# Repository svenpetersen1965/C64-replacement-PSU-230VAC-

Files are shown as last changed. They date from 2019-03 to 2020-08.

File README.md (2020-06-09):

# C64-replacement-PSU-230VAC-
This is a replacement PSU for the Commodore C64. The original PSUs from the 1980s and early 1990s tend to die and damage the connected C64, so it is recommended to get a new power supply for the C64.
This design is straight forward: a transformer, bridge rectifier and DC/DC converter for the 5VDC and a separat winding for the 9VAC. Nothing fancy. It was paid attention to use parts which are easily available (in Germany). Everything, except the 4 conductor cable for the output voltage are sourced from reichelt.de.
A further goal was a decent documentation.

Find some info on the required cable making <a href="http://tech.guitarsite.de/cable_making.html">on my website</a>

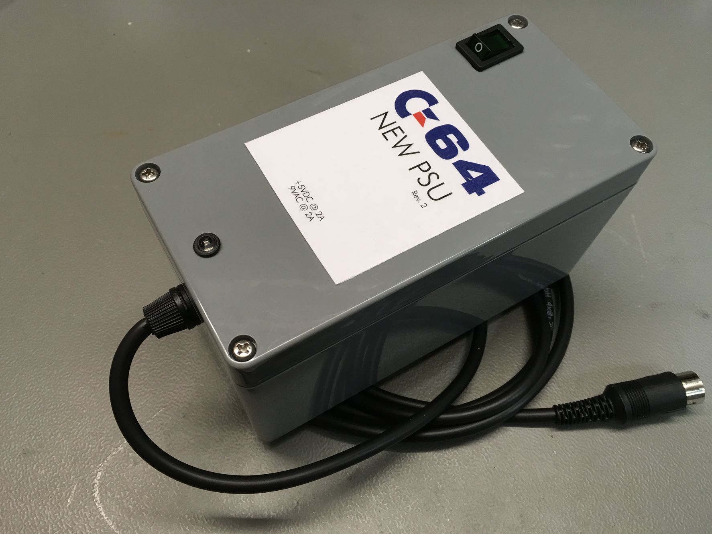
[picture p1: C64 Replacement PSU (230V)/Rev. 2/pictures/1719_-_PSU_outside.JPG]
C64 replacement PSU (outside)

      
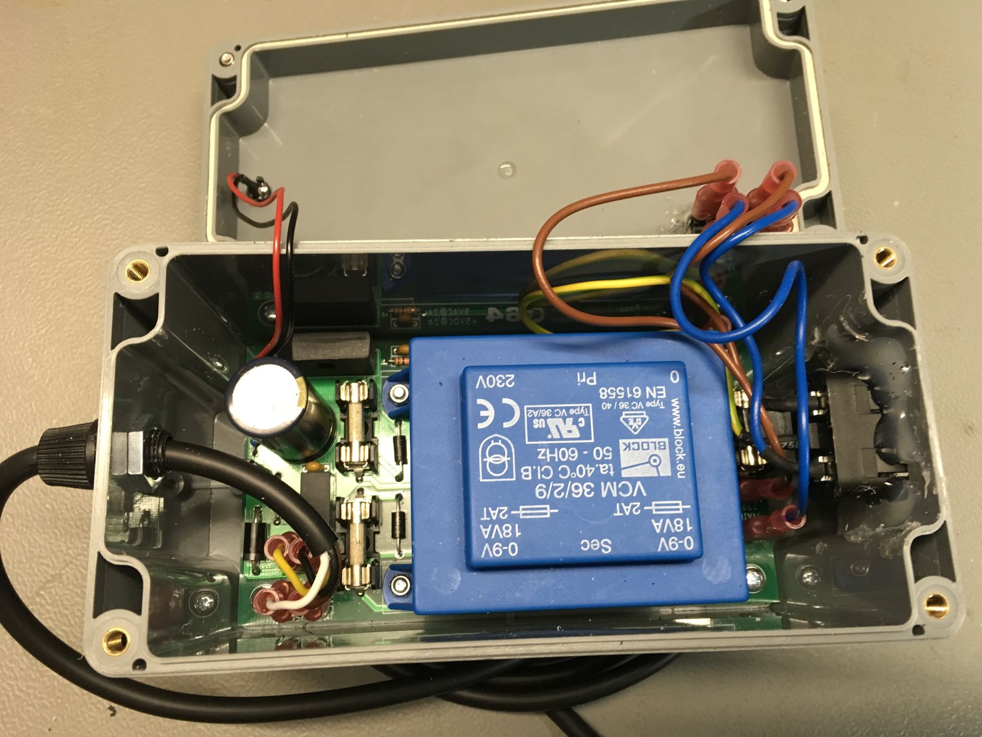
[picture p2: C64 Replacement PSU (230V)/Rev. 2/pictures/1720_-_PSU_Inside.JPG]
C64 replacement PSU (inside)


# three-way mains connector
The R/C combination (1MOhm/10nF) between GND and PE has a very positive effect: The capacitive mains couplings that usually happens in cheap SMPS, that are used for the S-Video/HDMI converters, the Pi1541 etc. is suppressed this way. No more flickering when touching the user port or cassette port. Thus, it is recommended to place those components and use a three-way appliance connector for mains.

# Calculation of the BOM prices
The BOM v2.0 was calculated. The total price of the components (case included) is 47.58€ (June 9th, 2020).

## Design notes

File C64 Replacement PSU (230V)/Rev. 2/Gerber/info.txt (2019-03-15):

       
       Board: C64_PS
       Rev.:  2
  
       Files:
       ======
  
       All Gerber files are generated in extended gerber format (RS274X)
       *.TOP        : Film top copper
       *.BOT        :  -"- bottom copper
       *.STC        :  -"- top soldermask 
       *.STS        :  -"- bottom soldermask
       *.PLC        :  -"- silk screen top
       *.DK         : Drills plated Through (Excellon)
       *.NDK        : Drills not plated Through (Excellon)
       *.OUT        : Board outline

       Board Size:
       ===========
       Length     :   134.0 mm
       Width      :   70.0 mm
       Thickness  :   1.6 mm
       Material   :   FR 4
       Copper     :   35 um
       Surface    :   HASL
       
       Remarks:
       ========

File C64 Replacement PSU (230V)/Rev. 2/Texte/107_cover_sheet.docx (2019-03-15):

Documentation

Commodore C64 Power Supply

(Replacement)

Project number: 107

Revision: 2

Date: 25.02.2019

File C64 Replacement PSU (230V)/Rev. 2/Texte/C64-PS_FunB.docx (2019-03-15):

Commodore C64 Power Supply (Replacement) Rev. 2

Functional description

The mains 230VAC are connected to the spade connectors J1 and J2. The primary coil of the transformer TR1 is protected by the fuse F3. C5 is the X2 capacitor for attenuation of interferences/transients.

TR1 is powered by 230VAC, the secondary coils provide 9VAC (nominal) @ 2A. One output is protected by F1. It provides the 9VAC for the C64. D2 acts as an overvoltage protection. It is bidirectional and suitable for AC.

The second output of the transformer is protected by F2. The bi-directional TVS diode D3 is placed for blocking transients. BR1 is a bridge rectifier. Its output voltage is smoothed by C1. IC1 is a dc/dc converter, which generates the+5VDC (max 2A) from its input voltage. C2, C3 and C4 are suppressing interferences. D4 is a reverse protection diode for the dc/dc converter.

The TVS diode D1 is protecting the output against over voltages and transients.

The output voltages are connected to the spade connectors (J4-J7).

The purpose of R2 and C6 is to provide a connection of the GND to PE, which could be connected to J8. This might be helpful in case some peripherals connected to the C64 (such as composite video/HDMI converter) are powered by poorly isolated PSUs. This is still in an experimental stage and not proved.

C64-PS_FunB.docx 14.03.2019 14:25 Erstellt von Sven Petersen Seite 2 von 2 Dok.-Nr.: 000-8-00-00

C64-PS_FunB.docx 14.03.2019 14:25 Drafted by Sven Petersen Page 1 of 1 Doc.-No.: 107-6-01-02

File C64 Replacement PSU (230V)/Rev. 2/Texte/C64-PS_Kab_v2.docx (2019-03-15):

Commodore C64 Power Supply (Replacement) Rev. 2

Cables

# DIN-Cable to Power the C64

Pinning of the power jack

Jack | Pin | Signal | Color
| 1 | n/c | -
| 2 | GND | black
| 3 | n/c | -
| 4 | n/c | -
| 5 | +5VDC | yellow
| 6 | 9VAC (1) | brown
| 7 | 9VAC (2) | white

The jack is shown here. It resembles the pinning of the plug seen from the solder side.

Old C64 models have the +5VDC connected to pin 4. This is no problem, since it is connected to pin 5 on the C64 mainboard.

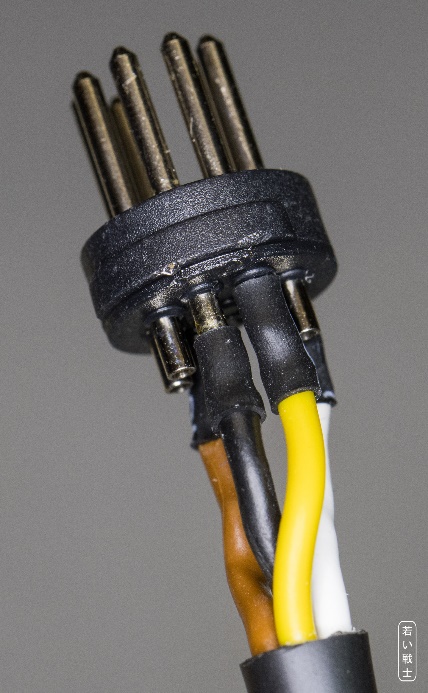
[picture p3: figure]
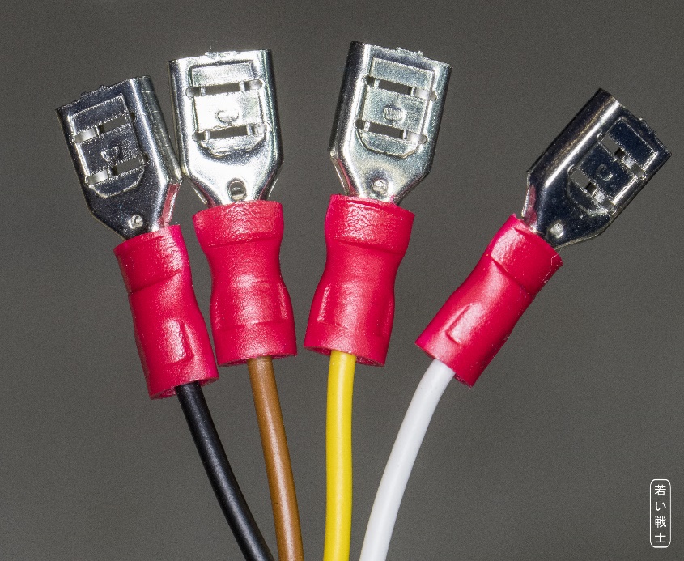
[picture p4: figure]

# LED-Cable

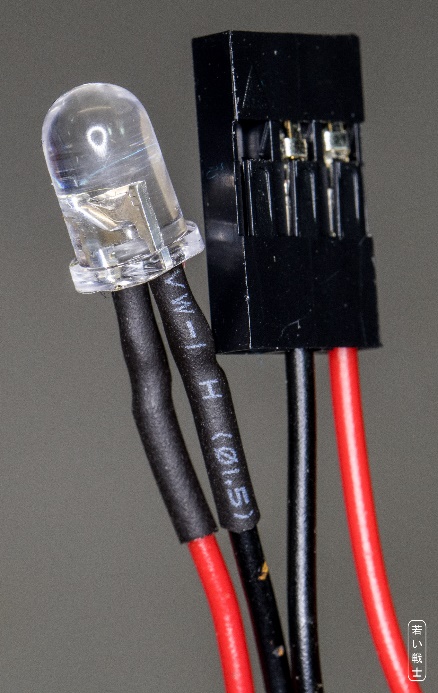
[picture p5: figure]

| The cathode of the LED is connected to the black wire, the anode is connected to the red wire. The pinning of the Dupont connector is +/-/+, so the orientation of the connector does not matter. The black wire is connected to the middle terminal, the red is connected to Pin 3. The pin header has a pin distance of 2.54mm (1/10“), any receptable, that is suitable can be soldered to the wires instead.

C64-PS_Kab_v2.docx 14.03.2019 14:25 Drafted by Sven Petersen Page 2 of 2 Doc.-No.: 107-6-04-02

C64-PS_Kab_v2.docx 14.03.2019 14:25 Drafted by Sven Petersen Page 1 of 1 Doc.-No.: 107-6-03-02

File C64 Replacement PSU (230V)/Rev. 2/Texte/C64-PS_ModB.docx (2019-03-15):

Commodore C64 Power Supply (Replacement) Rev. 2

Module Description

This module is a power supply unit for the Commodore C64. It is dimensioned for an input voltage of 230VAC and provides 9VAC@2A as well as +5VDC@2A, which is sufficient to power the C64. The output voltages are isolated against each other.

The dimensions of the PCB are suitable for fitting it into an RND 455-00220 plastic enclosure (reichelt.de).

The PE connector is not connected to the mounting holes. In case a metal case is used, a 3 prong mains connector is mandatory and the case has to be connected to PE.

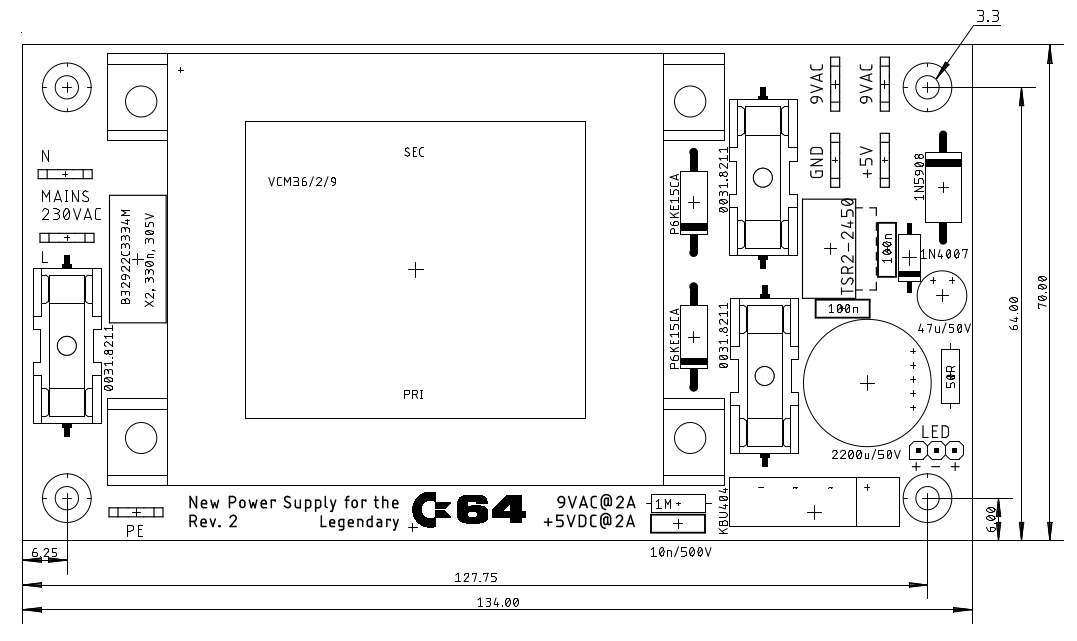
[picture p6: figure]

Figure 1: Dimensions of the PCB

# Pinning

### Spade connectors

6,3 x 0,8

Spade connector | Voltage
J1 | Mains (L)
J2 | Mains (N)
J8 | PE (not assembled)
J4 | 9VAC (1)
J5 | 9VAV (2)
J6 | +5V
J7 | GND (reference for +5V)

## LED

A blue LED (Vf=4,0V @ 20mA) is connected to J3. J3: Pinheader, RM2,54mm.

Pin | Signal
1 | LED+
2 | LED-
3 | LED+

For a red, green or yellow LED, the value of R1 should be 330Ω.

## Fuses

Fuse | Voltage | Value
F1 | 9VAC | 2AT
F2 | +5VAC | 2AT
F3 | Mains (230VAC) | 0,16AT

# Revision History

## Rev. 0 → Rev. 1

- PCB revision
- C5: footprint corrected
- D4: diode added

## Rev. 1 → Rev. 2

- PCB revision
- IC1: TRACO 2A version (it is still possible to place the RECOM 1.5A dc/dc converter).
- D1: different type
- J8, R2, C6: Experimental connection of GND and PE

C64-PS_ModB.docx 14.03.2019 14:26 Drafted by Sven Petersen Page 2 of 2 Doc.-No.: 107-6-01-02

C64-PS_ModB.docx 14.03.2019 14:26 Drafted by Sven Petersen Page 1 of 1 Doc.-No.: 107-6-01-02

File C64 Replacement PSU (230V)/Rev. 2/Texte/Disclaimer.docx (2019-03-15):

Disclaimer

Working with mains voltages can be harmful and cause death. Do not connect this PCB to mains (230VAC) unless you are trained in doing so and know the required safety regulations.

This PSU is a prototype, it is not certified in any way and might only be used as a prototype under laboratory conditions. Usage is at own risk.

The PSU is designed to be installed in a plastic case. In case a metal case is used, a 3 prong mains connector is required and the case has to be connected to PE in a suitable way.

The documentation is drafted to the best of my knowledge. The creator is not liable for the accuracy and completeness.

Disclaimer.docx 14.03.2019 14:24 Erstellt von Sven Petersen Seite 2 von 2 Dok.-Nr.: 000-8-00-00

Disclaimer.docx 14.03.2019 14:24 Drafted by Sven Petersen Page 1 of 1

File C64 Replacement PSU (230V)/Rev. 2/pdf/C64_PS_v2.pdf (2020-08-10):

# Documentation

## Commodore C64 Power Supply

## (Replacement)

## Project number: 107

## Revision: 2

## Date: 25.02.2019

Disclaimer.docx | 14.03.2019 14:24
Drafted by Sven Petersen | Page 1 of 1

### Disclaimer

Working with mains voltages can be harmful and cause death. Do not connect this PCB to mains (230VAC) unless you are trained in doing so and know the required safety regulations.

This PSU is a prototype, it is not certified in any way and might only be used as a prototype under laboratory conditions. Usage is at own risk.

The PSU is designed to be installed in a plastic case. In case a metal case is used, a 3 prong mains connector is required and the case has to be connected to PE in a suitable way.

The documentation is drafted to the best of my knowledge. The creator is not liable for the accuracy and completeness.


C64-PS_ModB.docx | | 14.03.2019 14:26
Drafted by Sven Petersen | Page 1 of 2 | Doc.-No.: 107-6-01-02

## Commodore C64 Power Supply (Replacement) Rev. 2

## Module Description

This module is a power supply unit for the Commodore C64. It is dimensioned for an input voltage of 230VAC and provides 9VAC@2A as well as +5VDC@2A, which is sufficient to power the C64. The output voltages are isolated against each other.

The dimensions of the PCB are suitable for fitting it into an RND 455-00220 plastic enclosure (reichelt.de).

The PE connector is not connected to the mounting holes. In case a metal case is used, a 3 prong mains connector is mandatory and the case has to be connected to PE.

Figure 1: Dimensions of the PCB

## Pinning

Spade connectors
6,3 x 0,8
Spade connector | Voltage
J1 | Mains (L)
J2 | Mains (N)
J8 | PE (not assembled)
J4 | 9VAC (1)
J5 | 9VAV (2)
J6 | +5V
J7 | GND (reference for +5V)

C64-PS_ModB.docx | | 14.03.2019 14:26
Drafted by Sven Petersen | Page 2 of 2 | Doc.-No.: 107-6-01-02

### LED

A blue LED (Vf=4,0V @ 20mA) is connected to J3. J3: Pinheader, RM2,54mm.

Pin | Signal
1 LED+
2 LED-
3 LED+
For a red, green or yellow LED, the value of R1 should be 330Ω.

### Fuses

Fuse | Voltage | Value
F1 | 9VAC | 2AT
F2 | +5VAC | 2AT
F3 | Mains (230VAC) | 0,16AT

## Revision History

### Rev. 0 → Rev. 1

- PCB revision
- C5: footprint corrected
- D4: diode added

### Rev. 1 → Rev. 2

- PCB revision
- IC1: TRACO 2A version (it is still possible to place the RECOM 1.5A dc/dc converter).
- D1: different type
- J8, R2, C6: Experimental connection of GND and PE

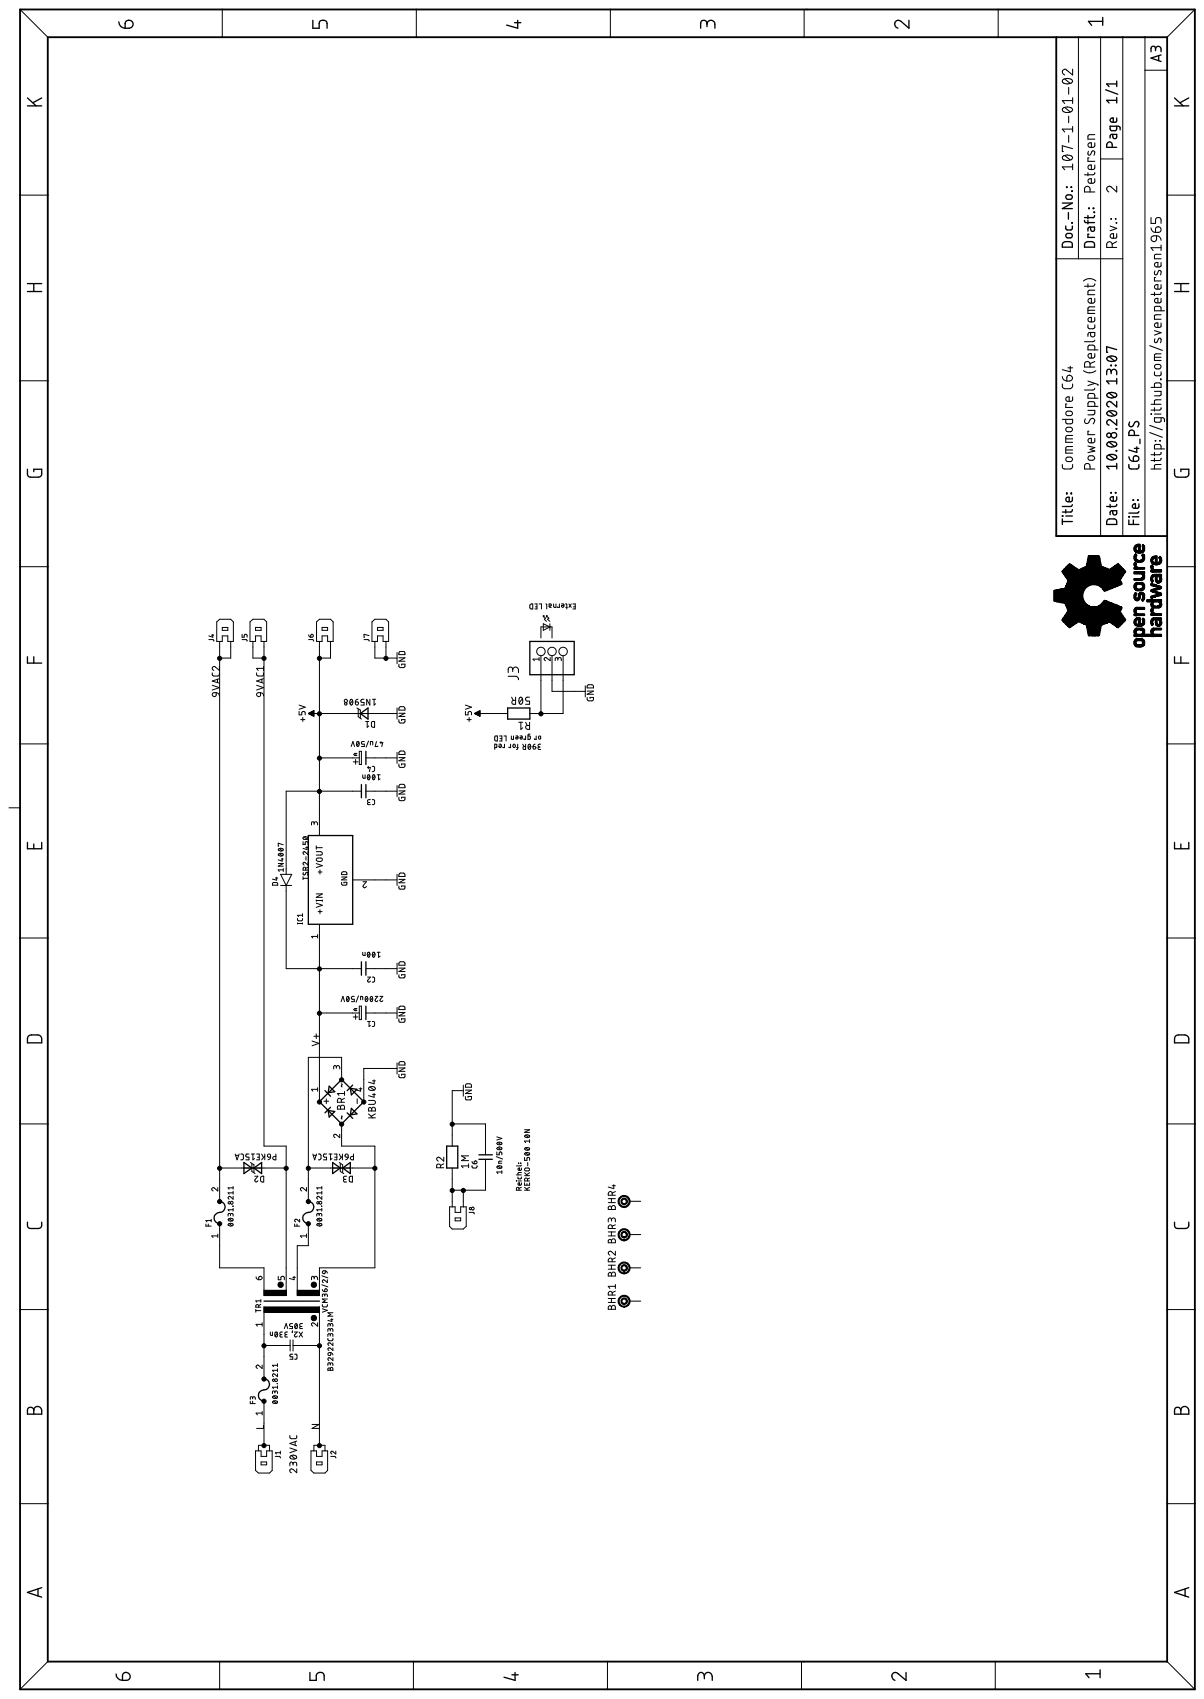
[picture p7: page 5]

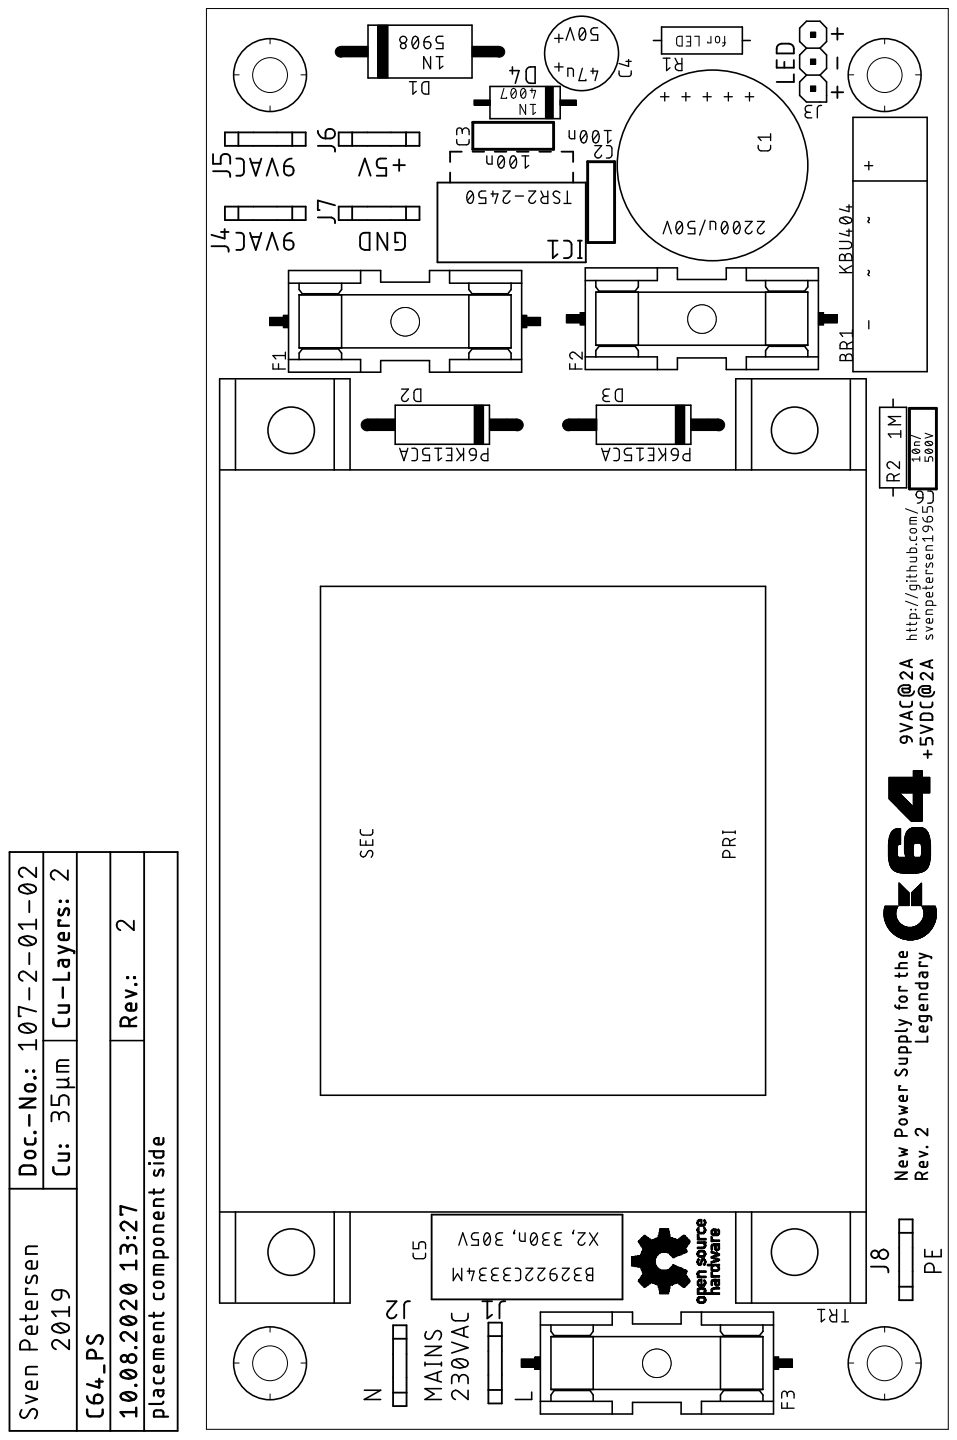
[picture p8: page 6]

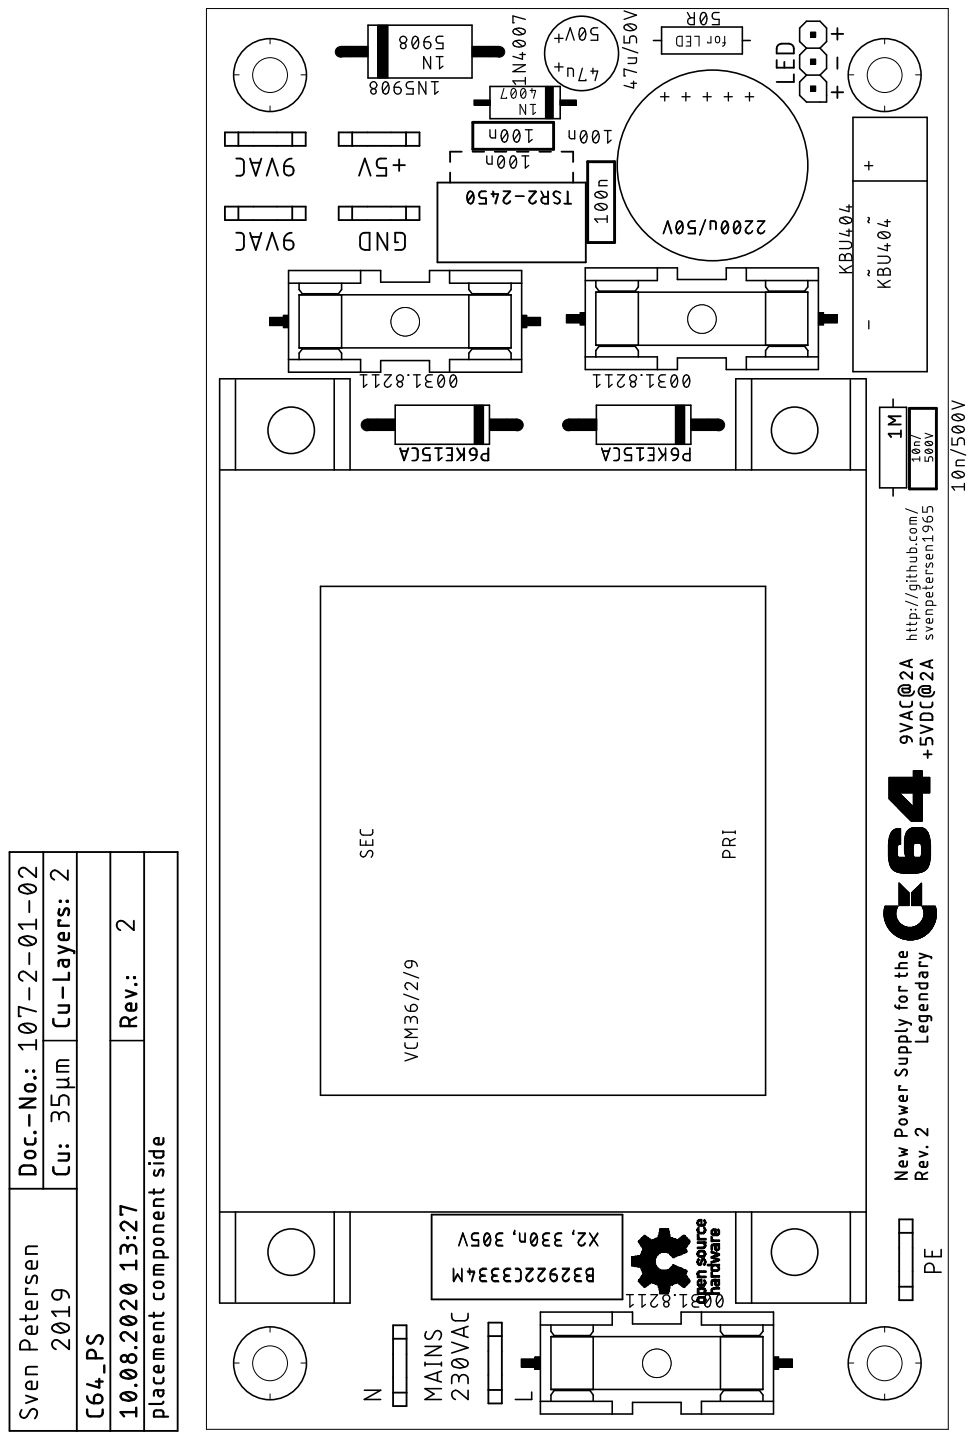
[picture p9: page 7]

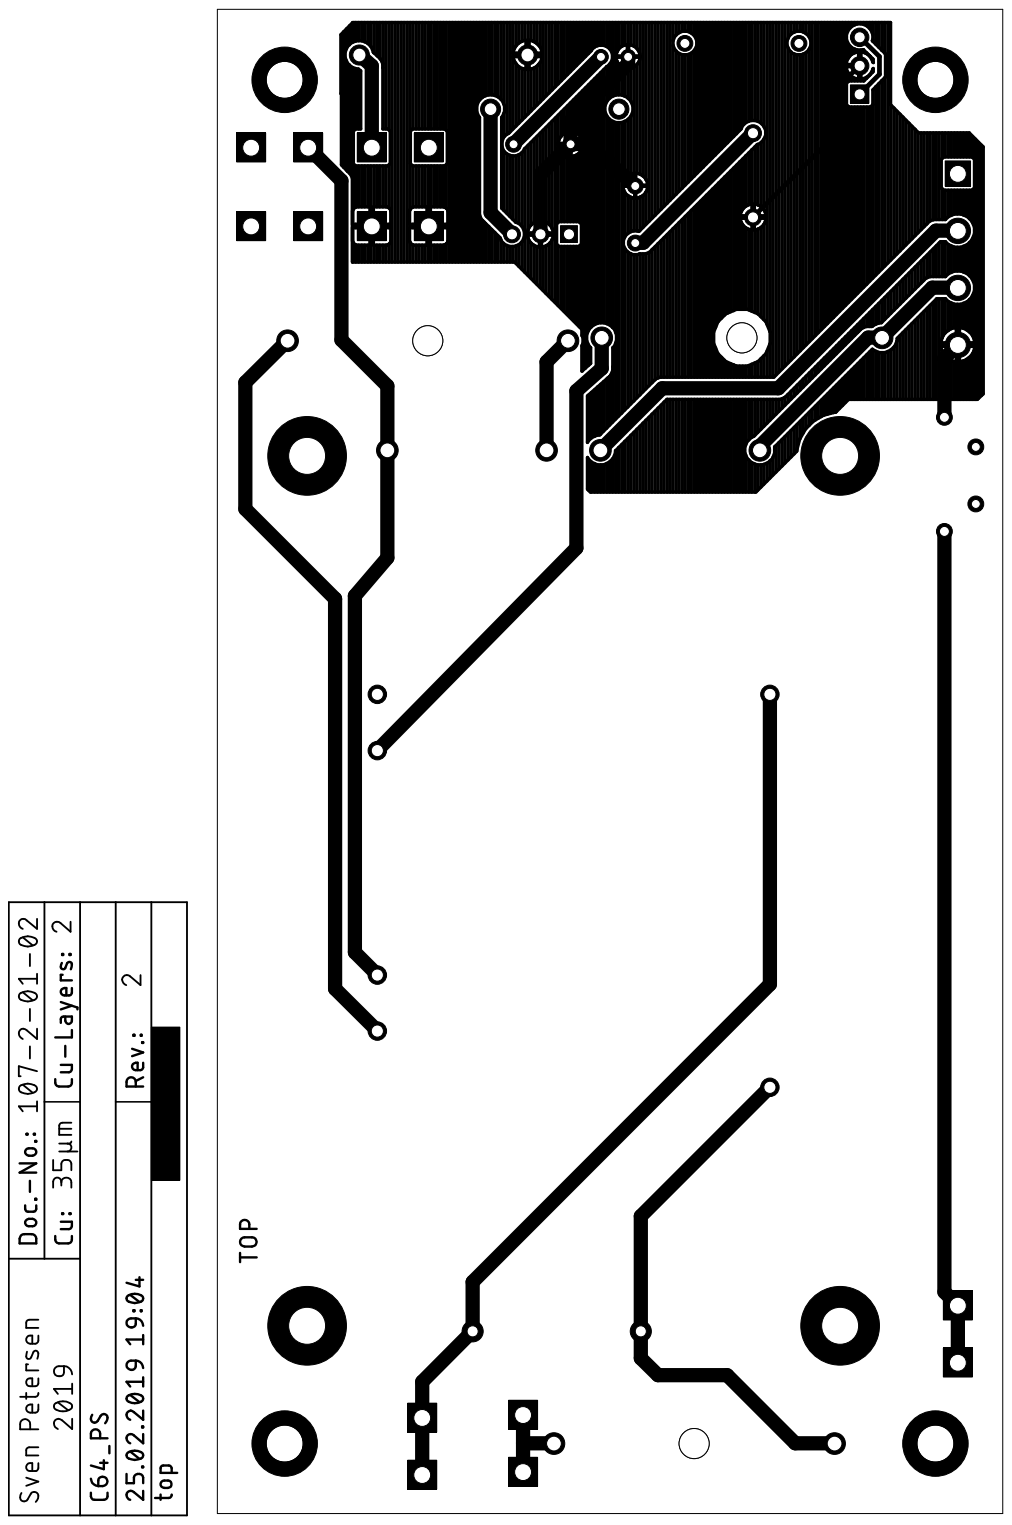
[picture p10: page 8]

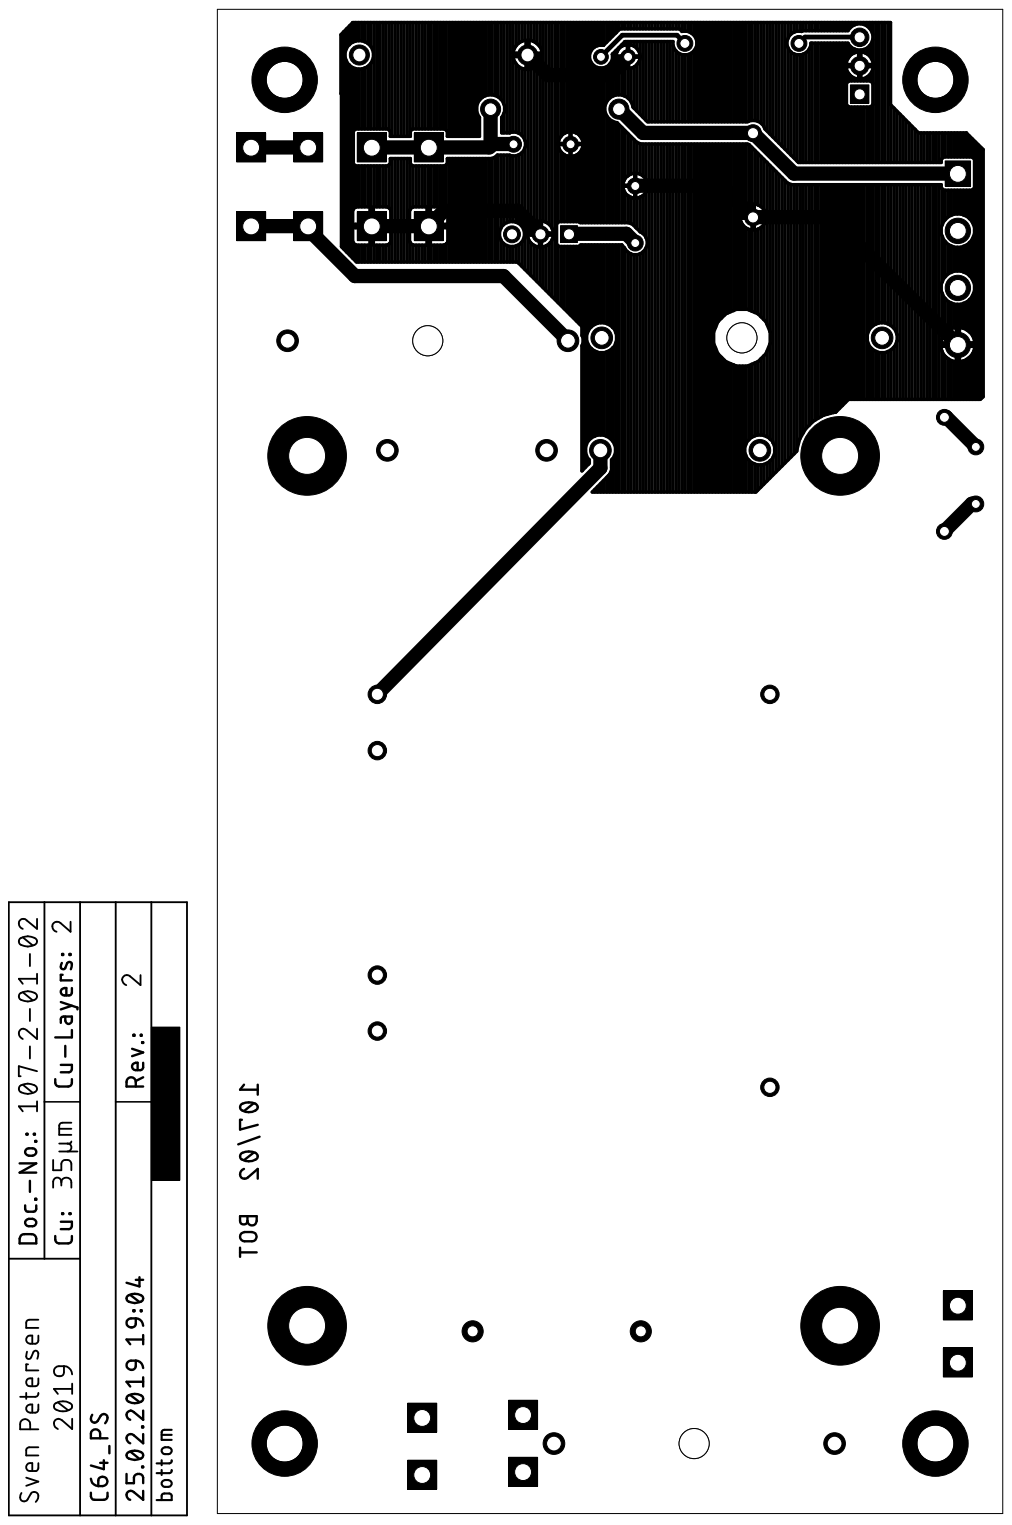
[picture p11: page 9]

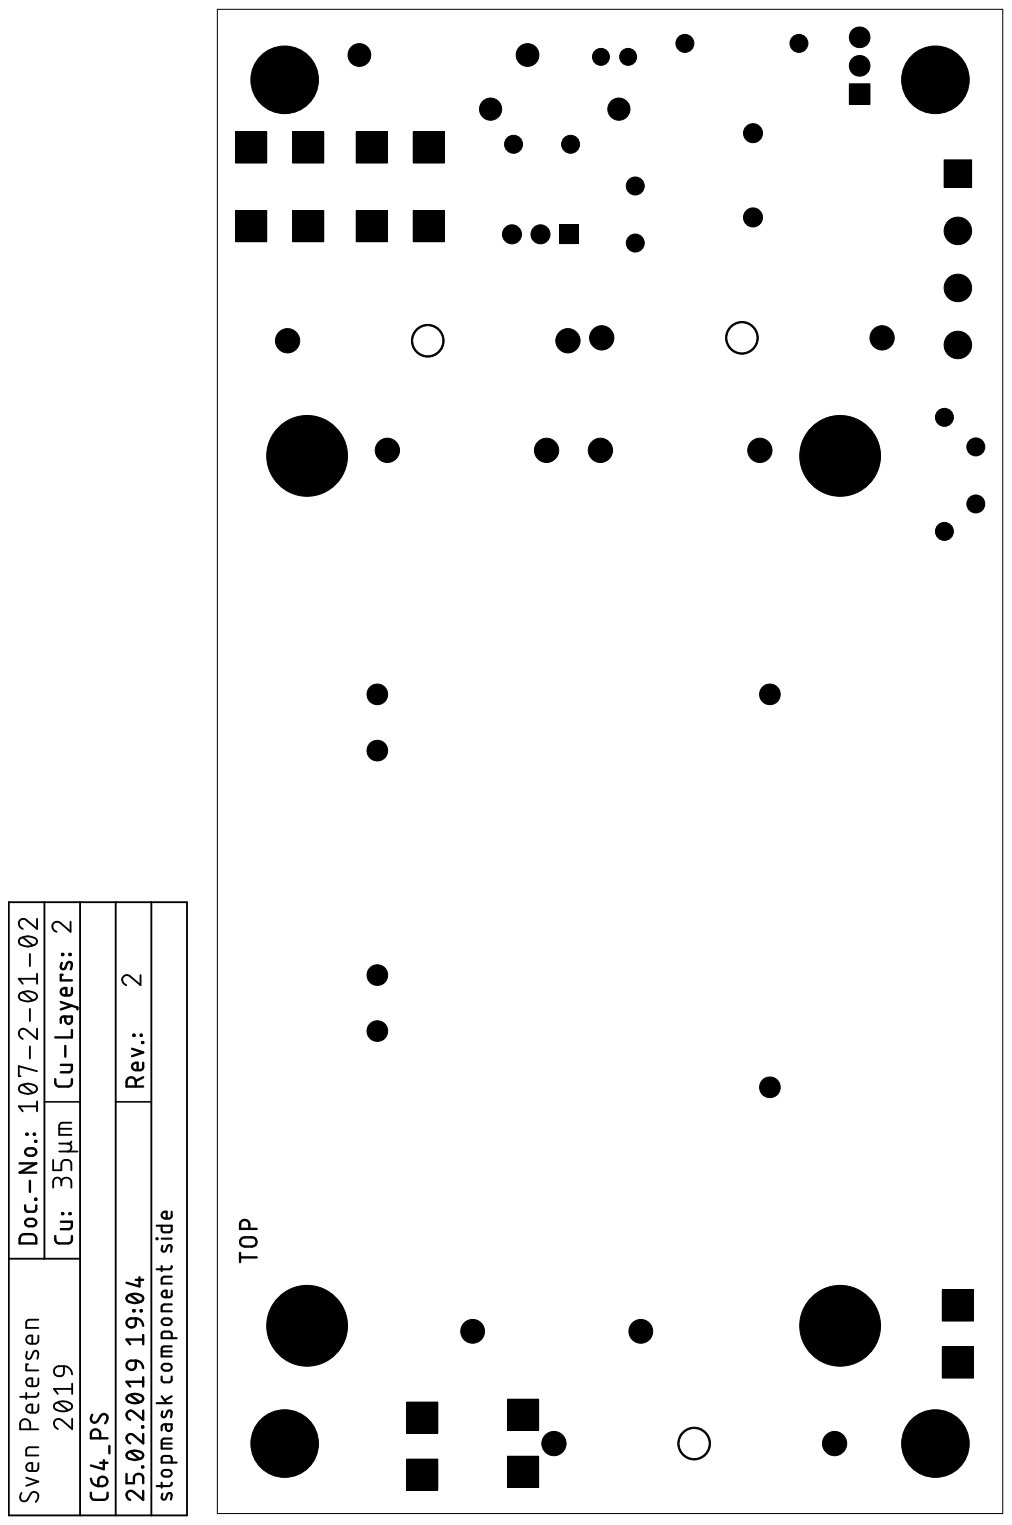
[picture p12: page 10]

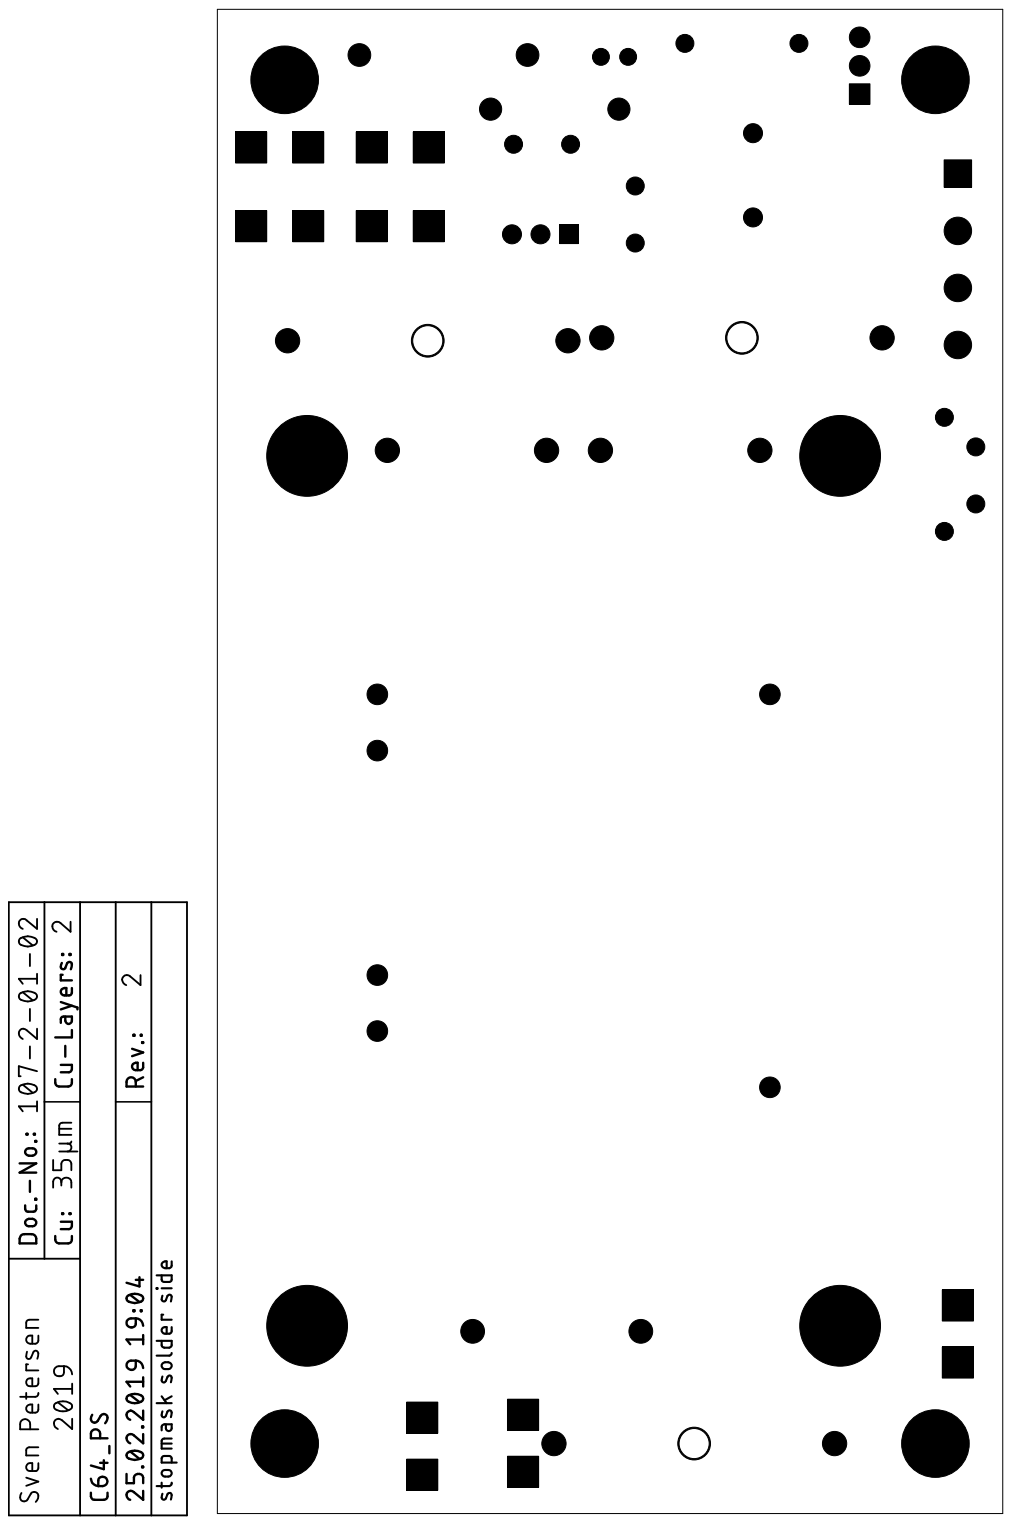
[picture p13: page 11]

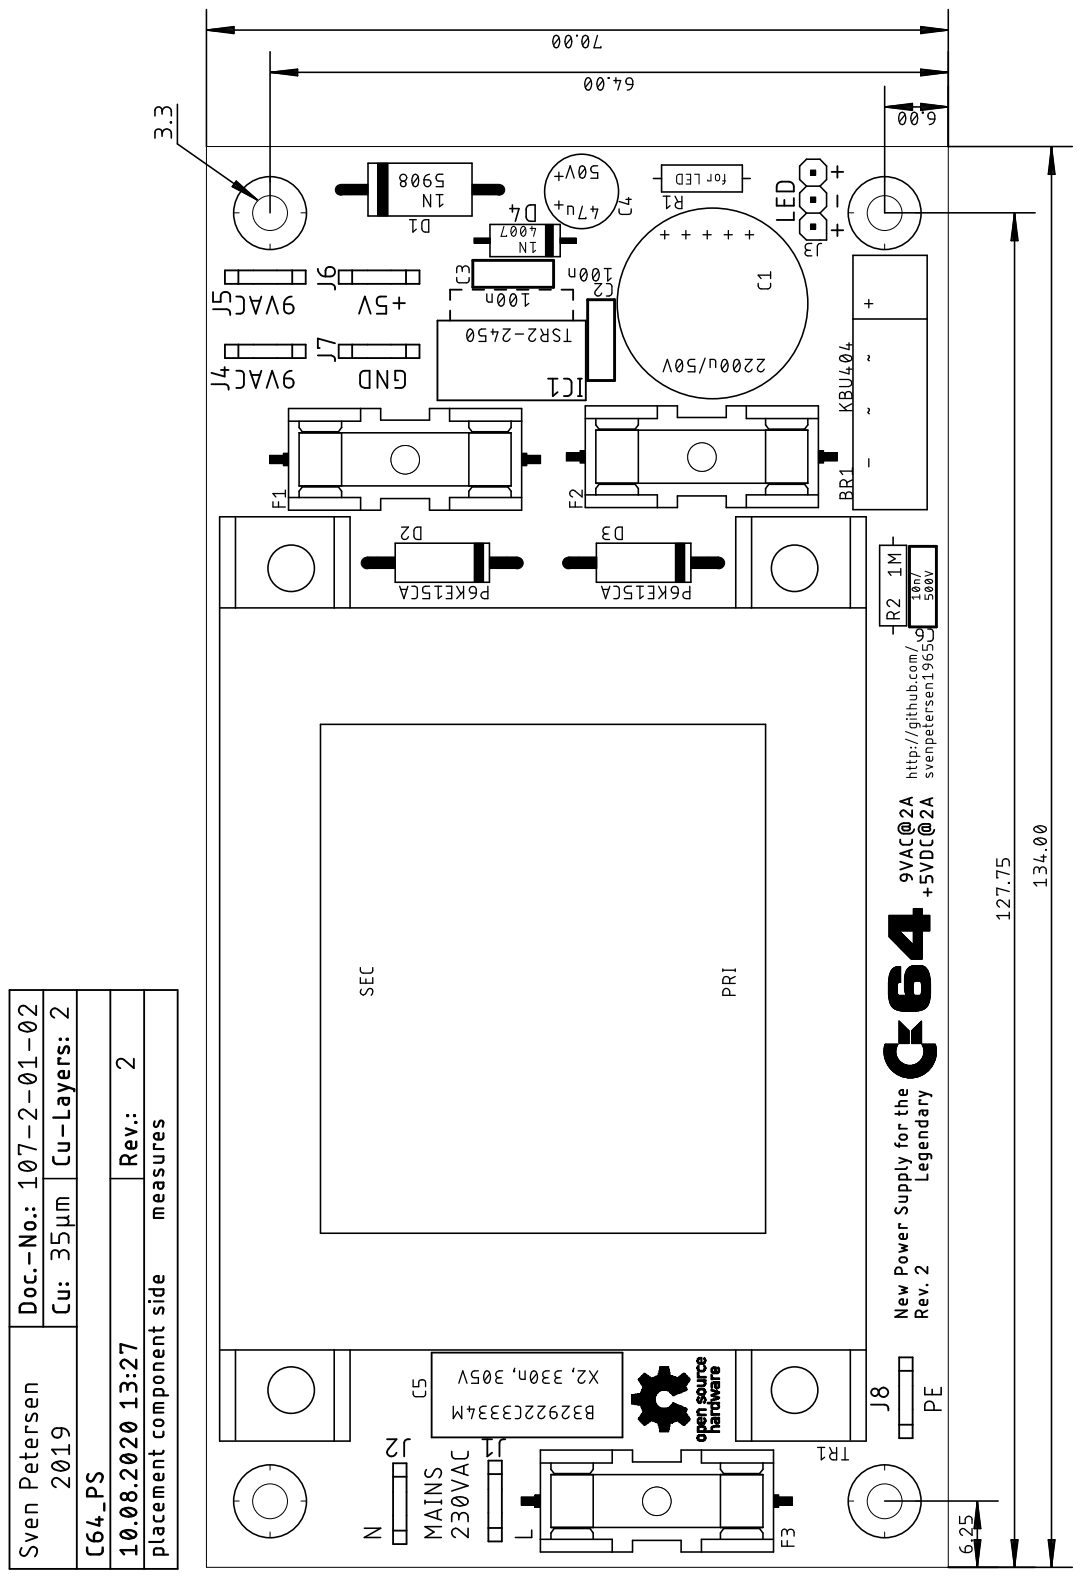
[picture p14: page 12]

C64-PS_FunB.docx | | 14.03.2019 14:25
Drafted by Sven Petersen | Page 1 of 1 | Doc.-No.: 107-6-01-02

### Commodore C64 Power Supply (Replacement) Rev. 2

### Functional description

The mains 230VAC are connected to the spade connectors J1 and J2. The primary coil of the transformer TR1 is protected by the fuse F3. C5 is the X2 capacitor for attenuation of interferences/transients.

TR1 is powered by 230VAC, the secondary coils provide 9VAC (nominal) @ 2A. One output is protected by F1. It provides the 9VAC for the C64. D2 acts as an overvoltage protection. It is bidirectional and suitable for AC.

The second output of the transformer is protected by F2. The bi-directional TVS diode D3 is placed for blocking transients. BR1 is a bridge rectifier. Its output voltage is smoothed by C1. IC1 is a dc/dc converter, which generates the+5VDC (max 2A) from its input voltage. C2, C3 and C4 are suppressing interferences. D4 is a reverse protection diode for the dc/dc converter.

The TVS diode D1 is protecting the output against over voltages and transients.

The output voltages are connected to the spade connectors (J4-J7).

The purpose of R2 and C6 is to provide a connection of the GND to PE, which could be connected to J8. This might be helpful in case some peripherals connected to the C64 (such as composite video/HDMI converter) are powered by poorly isolated PSUs. This is still in an experimental stage and not proved.

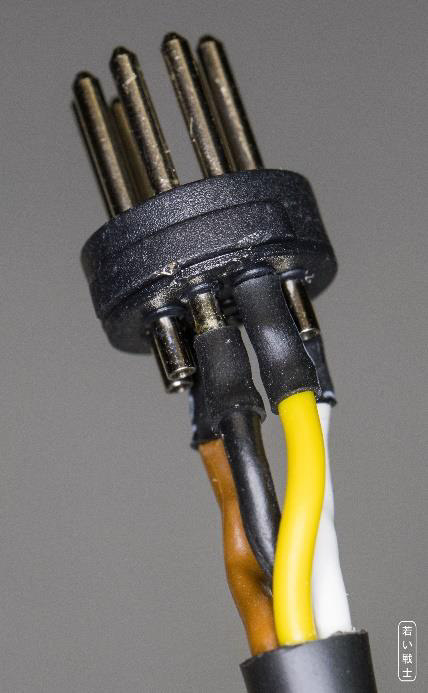
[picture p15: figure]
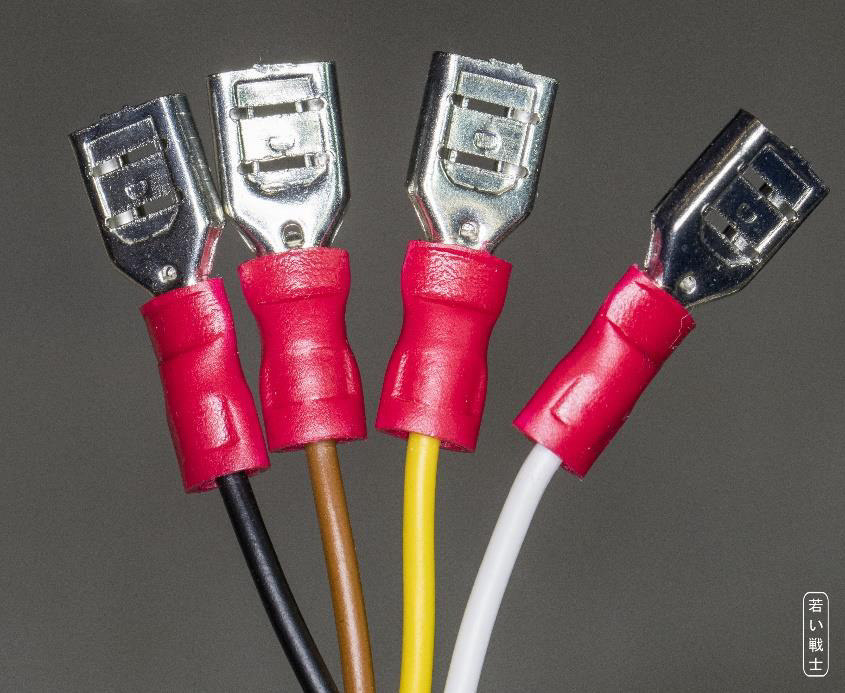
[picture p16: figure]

C64-PS_Kab_v2.docx | | 14.03.2019 14:25
Drafted by Sven Petersen | Page 1 of 2 | Doc.-No.: 107-6-03-02

### Commodore C64 Power Supply (Replacement) Rev. 2

### Cables

## DIN-Cable to Power the C64

Pinning of the power jack

Jack | Pin | Signal | Color
1 | n/c | -
2 | GND | black
3 | n/c | -
4 | n/c | -
5 | +5VDC | yellow
6 | 9VAC (1) | brown
7 | 9VAC (2) | white

The jack is shown here. It resembles the pinning of the plug seen from the solder side.

Old C64 models have the +5VDC connected to pin 4. This is no problem, since it is connected to pin 5 on the C64 mainboard.

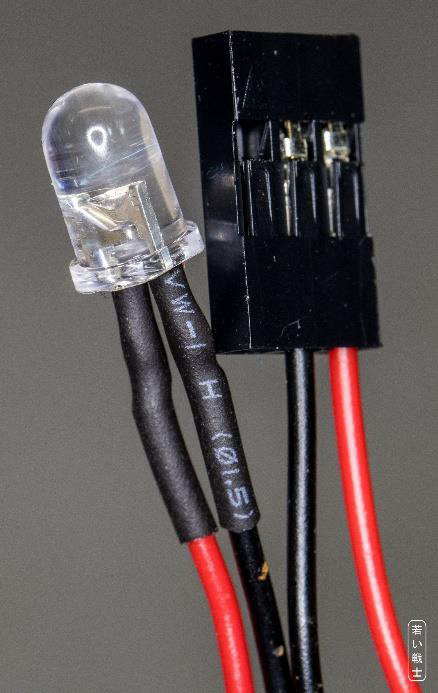
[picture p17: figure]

C64-PS_Kab_v2.docx | | 14.03.2019 14:25
Drafted by Sven Petersen | Page 2 of 2 | Doc.-No.: 107-6-04-02

## LED-Cable

The cathode of the LED is connected to the black wire, the anode is connected to the red wire. The pinning of the Dupont connector is +/-/+, so the orientation of the connector does not matter. The black wire is connected to the middle terminal, the red is connected to Pin 3.

The pin header has a pin distance of 2.54mm

### (1/10“), any receptable, that is suitable can be

soldered to the wires instead.

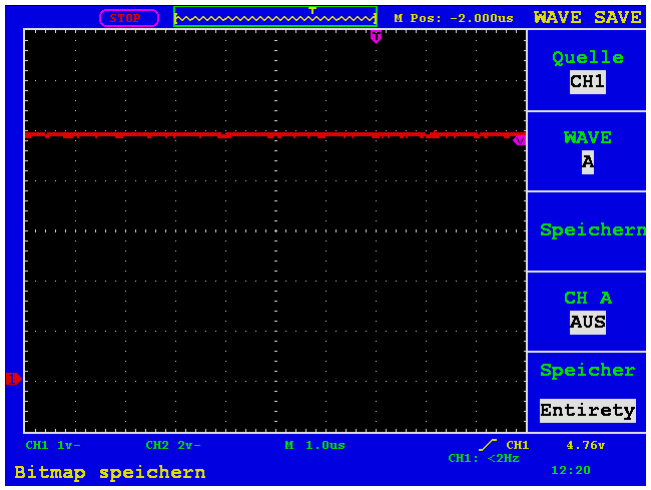
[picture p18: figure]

C64-PS_PrototypeTesting.docx | | 15.03.2019 09:34
Drafted by Sven Petersen | Page 1 of 5 | Doc.-No.: 107-6-04-02

### Commodore C64 Power Supply (Replacement) Rev. 2

### Prototype Test

## Measurements

Voltage | No load | C64 | Full load | Testing
+5VDC | +5.034V | +4.841V | +4.800V | Within -5% margin: ok
9VAC | 10.62V~ | 10.43V~ | 10.13V~ | Above nominal: ok

### The voltages of “no load” are measured on the DIN plug of the PSU. The other

measurements were done on the User Port. The C64 is a model C (ASSY 250469).

“Full load” means, that a C64 with an Ultimate II+ and a Commodore C2N Datasette are connected. The motor of the Datassette is running.

The measurements were conducted with a Fluke 89 IV multimeter.

## Oscilloscope view of the +5VDC

The +5VDC were measured at the User Port (Pin 2 and Pin1). The time division was set to 1.0µs/cm, which seems to be sufficient with a clock frequency of approximately 1MHz. The trigger was set to 4.76V (+5V – 5%).

No failure was detected. The wave form shown in Figure 1 was recorded in auto trigger mode, since the scope was never triggered.

Figure 1: +5VDC, DC-Coupling (1V/cm)

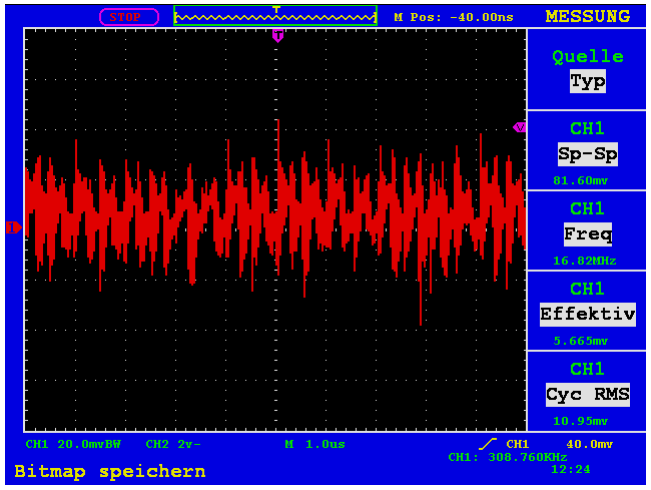
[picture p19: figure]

C64-PS_PrototypeTesting.docx | | 15.03.2019 09:34
Drafted by Sven Petersen | Page 2 of 5 | Doc.-No.: 107-6-05-02

Figure 2 shows the AC coupled signal. The vertical setting was 20.0mV/cm. The interferences are little (82mVpeak-peak).

Figure 2: +5VDC, AC-Coupling (20mV/cm)

Testing: ok

The measurements were conducted with a Peak-Tech 1190 oscilloscope. The condition was a “full
load” condition, the C64 was running and the Ultimate II+ was active.

## Long time testing

A long-time test over 5 hours was conducted by running the Diagnostic Rev. 586220. No failure was detected.

Testing: ok

## Thermal testing

The thermal testing was conducted under a full load condition (C64, Ultimate II+, Datassette). The components were initially at room temperature condition (25°C). A thermo couple was attached to the transformer, the case was closed except the mounting hole for the LED. It was occupied by the thermo couple. The test arrangement was running until the temperature of the transformer stabilized. This was after about four hours at 44.2°C.

Subsequently, the thermo couple was attached to the bridge rectifier. It was waited until the temperature stabilized. The reading was 45.4°C.

Finally, the thermo couple was attached to the DC/DC converter. Again, it was waited until the temperature stabilized. The reading was 47.8°C. AT this point, the elapsed thermal testing time was 7 hours. After switching off, the temperature sunk 35°C within 12 minutes.

The testing was conducted with a Fluke 89 IV multimeter and a corresponding thermo couple.

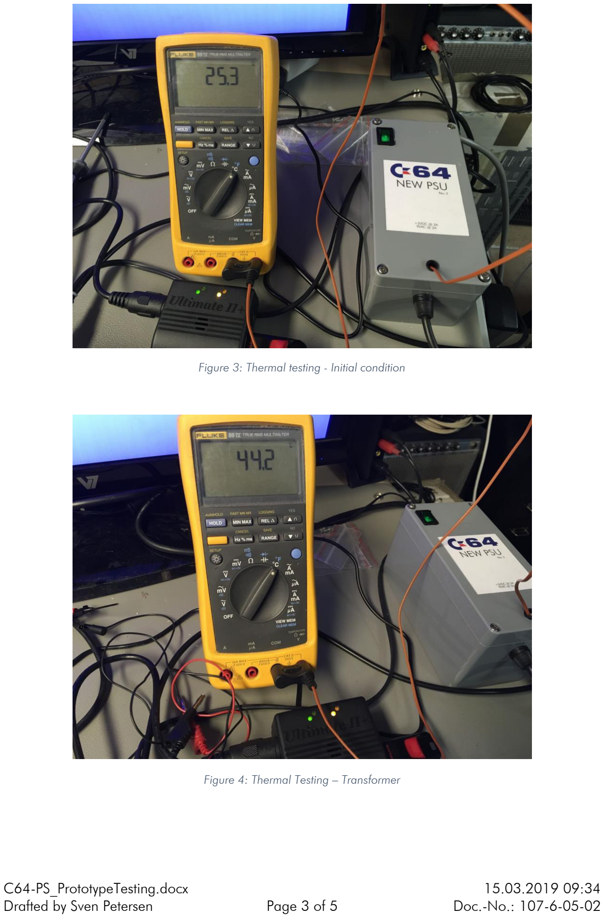
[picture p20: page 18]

C64-PS_PrototypeTesting.docx | | 15.03.2019 09:34
Drafted by Sven Petersen | Page 3 of 5 | Doc.-No.: 107-6-05-02

Figure 3: Thermal testing - Initial condition

Figure 4: Thermal Testing – Transformer

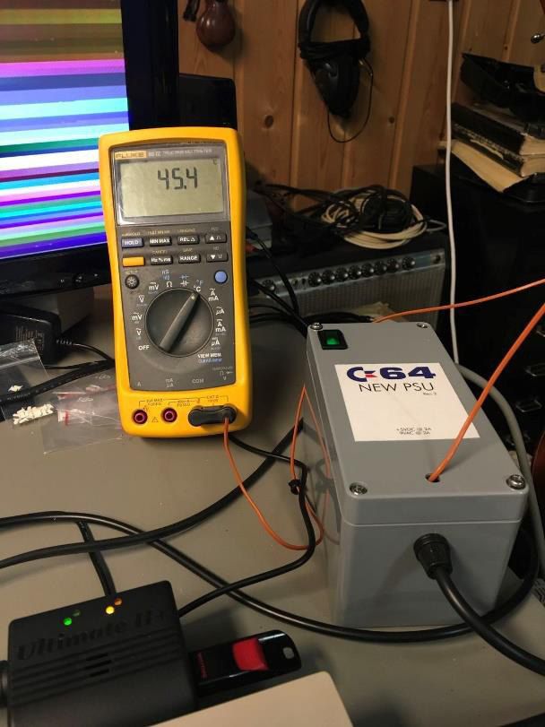
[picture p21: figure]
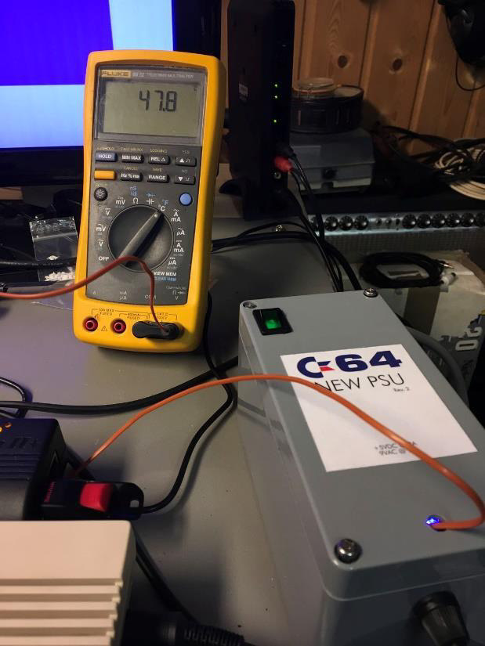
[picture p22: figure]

C64-PS_PrototypeTesting.docx | | 15.03.2019 09:34
Drafted by Sven Petersen | Page 4 of 5 | Doc.-No.: 107-6-05-02

Figure 5: Thermal Testing – Rectifier

Figure 6: Thermal Testing: DC/DC converter

Component | Measured (surface) | Rated (data sheet) | Testing
Transformer TR1 | 44.2°C | Tambient = 40°C | Note 1
Bridge Rectifier BR1 | 45.4°C | 125°C | ok
DC/DC-Converter IC1 | 47.8°C | 85°C | ok

C64-PS_PrototypeTesting.docx | | 15.03.2019 09:34
Drafted by Sven Petersen | Page 5 of 5 | Doc.-No.: 107-6-05-02

Note 1: The surface temperature is usually higher than the ambient temperature. The temperature might not be a problem, but it is close to the temperature ratings of the transformer. Ventilation openings in the enclosure are recommended.

The thermal testing was not conducted under best conditions. Instead of a defined load (maximum rating) from an electronic load, an estimated practical maximum load was used. A cassette motor permanently running for hours with an inserted tape for challenging the 9VAC does not have a practical use. The power consumption of the Ultimate II+ is not constant and it might not always reach its maximum.

The ambient temperature outside the PSU was 24°C. Testing in an environmental chamber was not conducted.

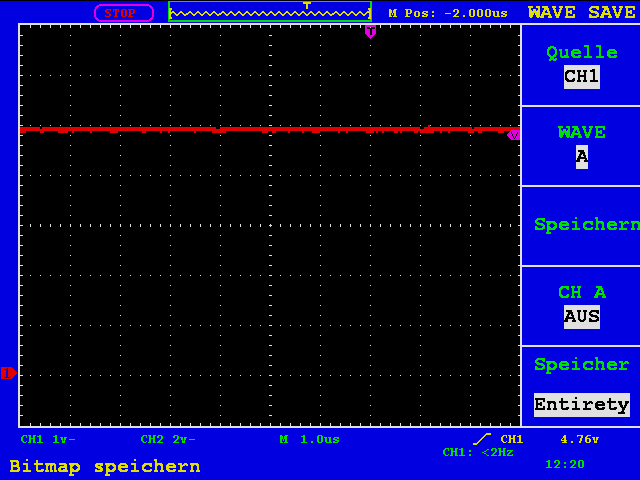
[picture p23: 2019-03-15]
C64 Replacement PSU (230V)/Rev. 2/pictures/5VDC_full_load_DC-Coupling.png

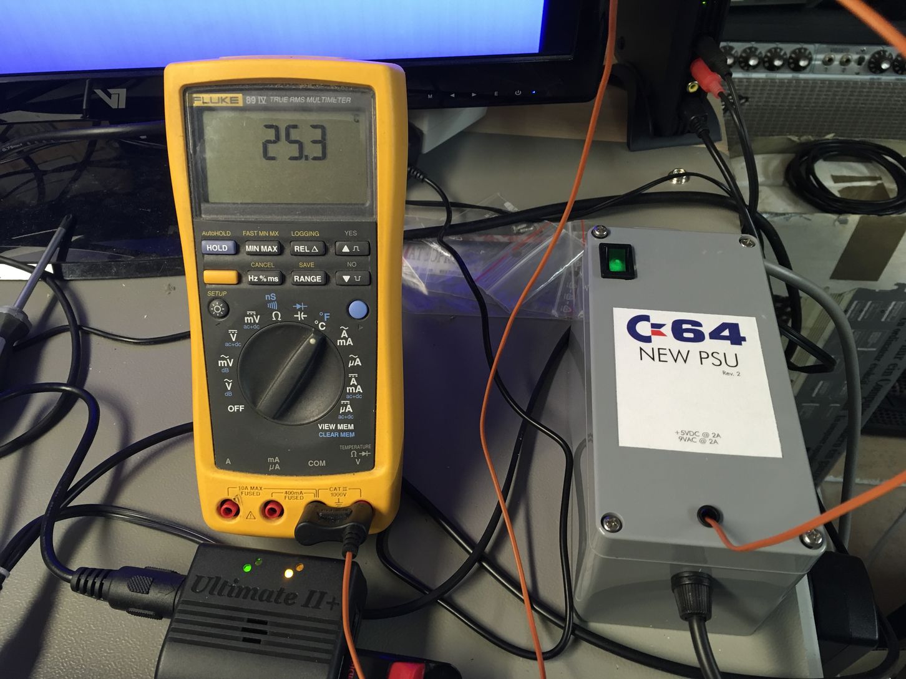
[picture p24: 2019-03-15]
C64 Replacement PSU (230V)/Rev. 2/pictures/1725_-_Thermal_Initial_condition.JPG

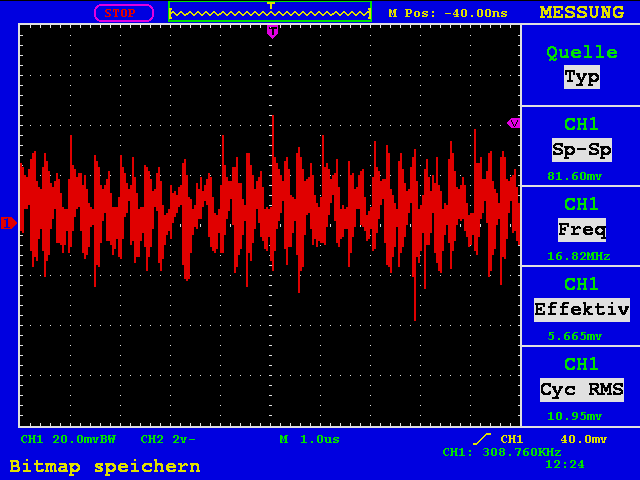
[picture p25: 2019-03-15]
C64 Replacement PSU (230V)/Rev. 2/pictures/5VDC_full_load_AC-Coupling.png

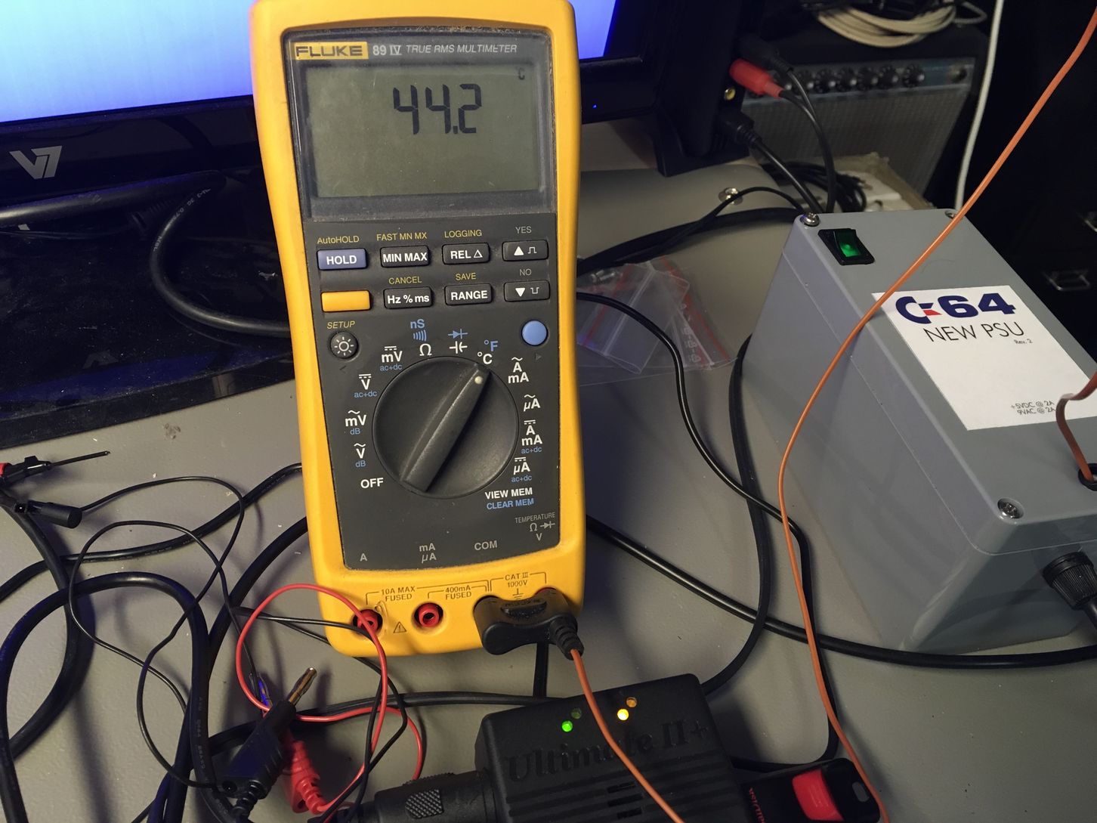
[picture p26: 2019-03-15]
C64 Replacement PSU (230V)/Rev. 2/pictures/1731_-_Thermal_Transformer.JPG

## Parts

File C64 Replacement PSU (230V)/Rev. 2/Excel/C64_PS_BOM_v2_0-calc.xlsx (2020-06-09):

C64 Power Supply (Replacement) Rev. 2
Bill of Material Rev. 2.0
Pos. | Each | Value | €/ea | € | Comment
1 | 1 | 107-2-01-02 | 1.00 € | 1.00 € | 2 layer, Cu 35µ, HASL, 134mm x 70mm, 1.6mm FR4
2 | 6 | 6,3 x 0,8 | 0.06 € | 0.36 € | Spade connector f. PCB, Reichelt RND 465-00018 (100ea)
3 | 1 | 6,3 x 0,8 | 0.06 € | 0.06 € | not assembled
4 | 1 | 1x03 | 0.03 € | 0.03 € | Pin header, Reichelt RND 205-00624
5 | 3 | 0031.8201 | 0.40 € | 1.20 € | Fuse holder, Schurter 0031.8201, Reichelt PL OGN-22,5
6 | 1 | 2A/T | 0.30 € | 0.30 € | glass fuse 5x 20, 2A t
7 | 2 | 2A/T | 0.30 € | 0.60 € | glass fuse 5x 20, 2A t
8 | 3 | 0,16A/T | 0.30 € | 0.90 € | glass fuse 5x 20, 0,16A t
9 | 2 | 100n | 0.06 € | 0.12 € | 100nF, 50V, RM5
10 | 1 | 2200u/50V | 0.99 € | 0.99 € | Elko Æ18mm/RM 7,5, 105°C, Reichelt RAD FC 2.200/50
11 | 1 | 47u/50V | 0.14 € | 0.14 € | Elko Æ7mm/RM 2,5, 105°C, Reichelt NHG-A 47U 50
12 | 1 | 49.9R | 0.03 € | 0.03 € | 49.9W, 1/4W
13 | 1 | B32922C3334 | 0.29 € | 0.29 € | X2-capacitor, EPCOS, 330 nF, 305 V, RM 15,0, Reichelt B32922C3334
14 | 1 | KBU404 | 0.45 € | 0.45 € | HY, bridge rectifier, 4A, Reichelt KBU4G
15 | 2 | P6KE15CA | 0.20 € | 0.40 € | Littlefuse, Reichelt P6KE 15CA
16 | 1 | 1N5908 | 0.36 € | 0.36 € | ST Micro, Reichelt 1N 5908
17 | 1 | TSR 2-2450 | 12.90 € | 12.90 € | 2A: Traco, Reichelt TSR 2-2450. (alternative 1.5A: DC/DC-converter RECOM, Reichelt R-78B50-15)
18 | 1 | VCM36/2/9 | 11.70 € | 11.70 € | Block VCM36/2/9, Trafo 230V/2x9V, 2A, Reichelt EI 66/23 209
19 | 1 | 4x0,75qmm | 3.80 € | 3.80 € | www.wamo-shop.de, Art.-Nr. V-198-003 or similar
20 | 1 | RND 455-00220 | 5.50 € | 5.50 € | RND, Reichelt RND 455-00220
21 | 4 | M3 x 6mm | 0.10 € | 0.40 €
22 | 6 | 6,3 x 0,8 mm, rot, ISO | 0.14 € | 0.84 € | Reichelt RND 465-00067
23 | 1 | MAS 70S | 0.47 € | 0.47 € | Reichelt MAS 70S
24 | 1 | Strain-reliefe 5,0-6,8mm | 0.79 € | 0.79 € | Reichelt KAZU 1
25 | 1 | mains cable 2p. Euro-double connector | 0.00 € | 0.00 €
26 | 1 | Einbaustecker C8 | 0.93 € | 0.93 € | Mains power cable panel connector, European Design C8, Reichelt B-AC-E
27 | 1 | L-53MBD BLUE | 0.60 € | 0.60 € | Kingbright 5mm LED, Reichelt SLK 5MM BL
28 | 1 | RTC-51 | 0.06 € | 0.06 € | Mounting clip for LED 5 mm, Reichelt MONTAGERING 5MM
29 | 1 | Dupont Crimp housing 3p | 0.25 € | 0.25 € | for LED
30 | 2 | Dupont Crimp contacts, female | 0.06 € | 0.12 € | for LED
31 | 1 | wire, 0.25mm² red | 0.10 € | 0.10 €
32 | 1 | wire, 0.25mm² black | 0.10 € | 0.10 €
33 | 2 | shrinkable sleeve | 0.01 € | 0.02 € | for LED
34 | 1 | wire, 0.75mm², blue | 0.15 € | 0.15 € | for C8 mains connector
35 | 1 | wire 0.75 mm², black | 0.15 € | 0.15 € | for C8 mains connector
36 | 1 | shrinkable sleeve | 0.01 € | 0.01 € | for C8 mains connector
37 | 2 | screw M3x16, flathead | 0.10 € | 0.20 € | for C8 mains connector
38 | 6 | Nuit M3, self locking | 0.10 € | 0.60 € | for C8 mains connector and transformer
39 | 6 | Washer 3,2 | 0.05 € | 0.30 € | for C8 mains connector and transformer
40 | 2 | screw M3x8 | 0.10 € | 0.20 € | for transformer
41 | 1 | 1N4007 | 0.02 € | 0.02 €
42 | 1 | 1M | 0.02 € | 0.02 € | not assembled
43 | 1 | 10n/500V | 0.12 € | 0.12 € | not assembled, Reichelt KERKO-500 10N
44 |  |  | Total | 47.58 €

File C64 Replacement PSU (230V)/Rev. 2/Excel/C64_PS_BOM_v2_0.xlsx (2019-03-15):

C64 Power Supply (Replacement) Rev. 2
Bill of Material Rev. 2.0
Pos. | Each | Value | Footprint | Ref.-No. | Comment
1 | 1 | 107-2-01-02 | 2 layer | PCB Rev. 2 | 2 layer, Cu 35µ, HASL, 134mm x 70mm, 1.6mm FR4
2 | 6 | 6,3 x 0,8 | FLA6,3 | J1, J2, J4, J5, J6, J7 | Spade connector f. PCB, Reichelt RND 465-00018 (100ea)
3 | 1 | 6,3 x 0,8 | FLA6,3 | J8 | not assembled
4 | 1 | 1x03 | 1X03 | J3 | Pin header, Reichelt RND 205-00624
5 | 3 | 0031.8201 | 0031.8201 | (F1), (F2), (F3) | Fuse holder, Schurter 0031.8201, Reichelt PL OGN-22,5
6 | 1 | 2A/T | 5x20mm | F1 | glass fuse 5x 20, 2A t
7 | 2 | 2A/T | 5x20mm | F2 | glass fuse 5x 20, 2A t
8 | 3 | 0,16A/T | 5x20mm | F3 | glass fuse 5x 20, 0,16A t
9 | 2 | 100n | C-5 | C2, C3 | 100nF, 50V, RM5
10 | 1 | 2200u/50V | C18/7,5 | C1 | Elko Æ18mm/RM 7,5, 105°C, Reichelt RAD FC 2.200/50
11 | 1 | 47u/50V | C07/2,5 | C4 | Elko Æ7mm/RM 2,5, 105°C, Reichelt NHG-A 47U 50
12 | 1 | 49.9R | R-10 | R1 | 49.9W, 1/4W
13 | 1 | B32922C3334 | C-18x8-RM15 | C5 | X2-capacitor, EPCOS, 330 nF, 305 V, RM 15,0, Reichelt B32922C3334
14 | 1 | KBU404 | KBU | BR1 | HY, bridge rectifier, 4A, Reichelt KBU4G
15 | 2 | P6KE15CA | CB417 | D2, D3 | Littlefuse, Reichelt P6KE 15CA
16 | 1 | 1N5908 | CB429 | D1 | ST Micro, Reichelt 1N 5908
17 | 1 | TSR 2-2450 | TSR 2 | IC1 | 2A: Traco, Reichelt TSR 2-2450. (alternative 1.5A: DC/DC-converter RECOM, Reichelt R-78B50-15)
18 | 1 | VCM36/2/9 | VCM36_2_9 | TR1 | Block VCM36/2/9, Trafo 230V/2x9V, 2A, Reichelt EI 66/23 209
19 | 2m | 4x0,75qmm | cable |  | www.wamo-shop.de, Art.-Nr. V-198-003 or similar
20 | 1 | RND 455-00220 | enclosure |  | RND, Reichelt RND 455-00220
21 | 4 | M3 x 6mm | screw
22 | 6 | 6,3 x 0,8 mm, rot, ISO | spade terminal |  | Reichelt RND 465-00067
23 | 1 | MAS 70S | DIN connector 7p |  | Reichelt MAS 70S
24 | 1 | Strain-reliefe 5,0-6,8mm | Strain-relieve |  | Reichelt KAZU 1
25 | 1 | mains cable 2p. Euro-double connector
26 | 1 | Einbaustecker C8 |  |  | Mains power cable panel connector, European Design C8, Reichelt B-AC-E
27 | 1 | L-53MBD BLUE | 5mm LED, blau |  | Kingbright 5mm LED, Reichelt SLK 5MM BL
28 | 1 | RTC-51 | RTC-51 |  | Mounting clip for LED 5 mm, Reichelt MONTAGERING 5MM
29 | 1 | Dupont Crimp housing 3p |  |  | for LED
30 | 2 | Dupont Crimp contacts, female |  |  | for LED
31 | 20cm | wire, 0.25mm² red
32 | 20cm | wire, 0.25mm² black
33 | 2cm | shrinkable sleeve |  |  | for LED
34 | 20cm | wire, 0.75mm², blue |  |  | for C8 mains connector
35 | 20cm | wire 0.75 mm², black |  |  | for C8 mains connector
36 | 3cm | shrinkable sleeve |  |  | for C8 mains connector
37 | 2 | screw M3x16, flathead |  |  | for C8 mains connector
38 | 6 | Nuit M3, self locking |  |  | for C8 mains connector and transformer
39 | 6 | Washer 3,2 |  |  | for C8 mains connector and transformer
40 | 2 | screw M3x8 |  |  | for transformer
41 | 1 | 1N4007 | DO-41 | D4
42 | 1 | 1M | R-10 | R2 | not assembled
43 | 1 | 10n/500V | C-5 | C6 | not assembled, Reichelt KERKO-500 10N

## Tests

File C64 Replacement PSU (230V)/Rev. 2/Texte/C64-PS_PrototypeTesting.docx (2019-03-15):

Commodore C64 Power Supply (Replacement) Rev. 2

Prototype Test

# Measurements

Voltage | No load | C64 | Full load | Testing
+5VDC | +5.034V | +4.841V | +4.800V | Within -5% margin: ok
9VAC | 10.62V~ | 10.43V~ | 10.13V~ | Above nominal: ok

The voltages of “no load” are measured on the DIN plug of the PSU. The other measurements were done on the User Port. The C64 is a model C (ASSY 250469).

“Full load” means, that a C64 with an Ultimate II+ and a Commodore C2N Datasette are connected. The motor of the Datassette is running.

The measurements were conducted with a Fluke 89 IV multimeter.

# Oscilloscope view of the +5VDC

The +5VDC were measured at the User Port (Pin 2 and Pin1). The time division was set to 1.0µs/cm, which seems to be sufficient with a clock frequency of approximately 1MHz. The trigger was set to 4.76V (+5V – 5%).

No failure was detected. The wave form shown in Figure 1 was recorded in auto trigger mode, since the scope was never triggered.


Figure 1: +5VDC, DC-Coupling (1V/cm)

Figure 2 shows the AC coupled signal. The vertical setting was 20.0mV/cm. The interferences are little (82mVpeak-peak).


Figure 2: +5VDC, AC-Coupling (20mV/cm)

Testing: ok

The measurements were conducted with a Peak-Tech 1190 oscilloscope. The condition was a “full load” condition, the C64 was running and the Ultimate II+ was active.

# Long time testing

A long-time test over 5 hours was conducted by running the Diagnostic Rev. 586220. No failure was detected.

Testing: ok

# Thermal testing

The thermal testing was conducted under a full load condition (C64, Ultimate II+, Datassette). The components were initially at room temperature condition (25°C). A thermo couple was attached to the transformer, the case was closed except the mounting hole for the LED. It was occupied by the thermo couple. The test arrangement was running until the temperature of the transformer stabilized. This was after about four hours at 44.2°C.

Subsequently, the thermo couple was attached to the bridge rectifier. It was waited until the temperature stabilized. The reading was 45.4°C.

Finally, the thermo couple was attached to the DC/DC converter. Again, it was waited until the temperature stabilized. The reading was 47.8°C. AT this point, the elapsed thermal testing time was 7 hours. After switching off, the temperature sunk 35°C within 12 minutes.

The testing was conducted with a Fluke 89 IV multimeter and a corresponding thermo couple.


Figure 3: Thermal testing - Initial condition


Figure 4: Thermal Testing – Transformer

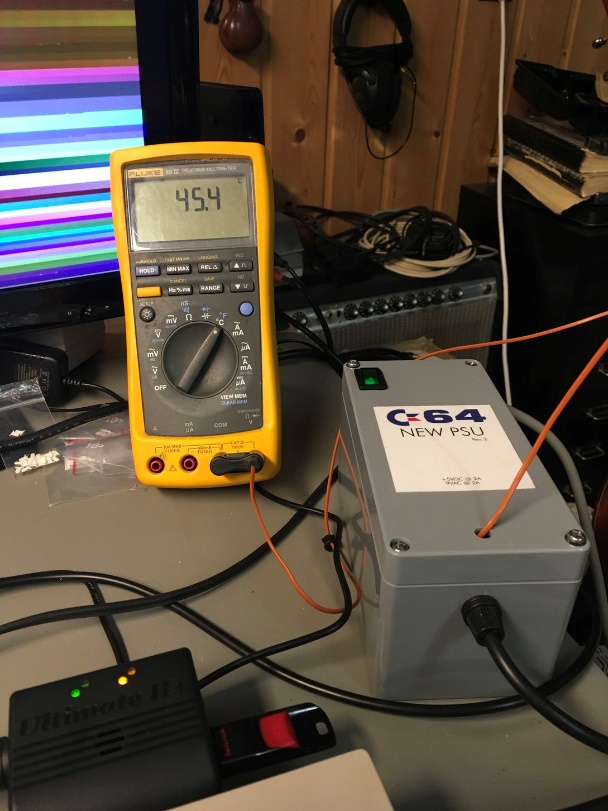
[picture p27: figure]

Figure 5: Thermal Testing – Rectifier

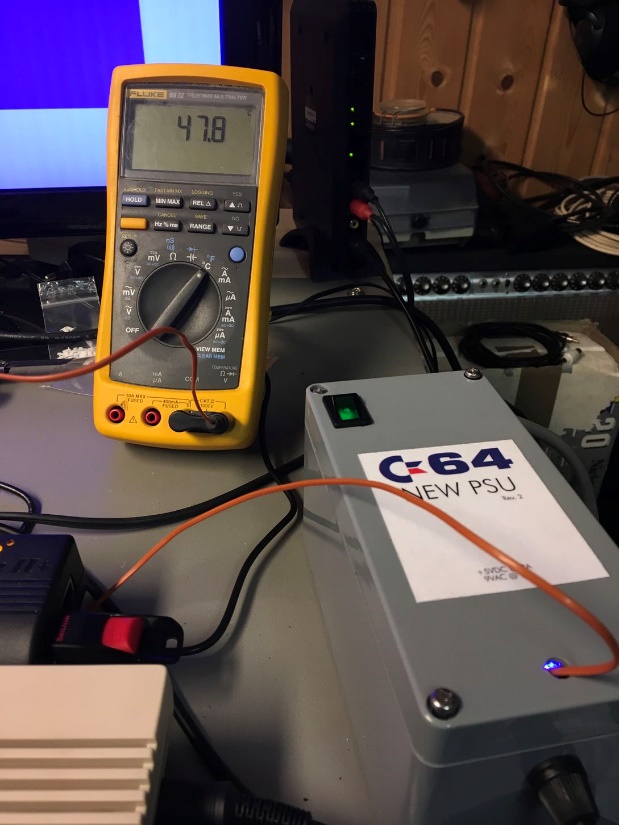
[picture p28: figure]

Figure 6: Thermal Testing: DC/DC converter

Component | Measured (surface) | Rated (data sheet) | Testing
Transformer TR1 | 44.2°C | Tambient = 40°C | Note 1
Bridge Rectifier BR1 | 45.4°C | 125°C | ok
DC/DC-Converter IC1 | 47.8°C | 85°C | ok

Note 1: The surface temperature is usually higher than the ambient temperature. The temperature might not be a problem, but it is close to the temperature ratings of the transformer. Ventilation openings in the enclosure are recommended.

The thermal testing was not conducted under best conditions. Instead of a defined load (maximum rating) from an electronic load, an estimated practical maximum load was used. A cassette motor permanently running for hours with an inserted tape for challenging the 9VAC does not have a practical use. The power consumption of the Ultimate II+ is not constant and it might not always reach its maximum.

The ambient temperature outside the PSU was 24°C. Testing in an environmental chamber was not conducted.

C64-PS_PrototypeTesting.docx 15.03.2019 09:34 Drafted by Sven Petersen Page 2 of 2 Doc.-No.: 107-6-05-02

C64-PS_PrototypeTesting.docx 15.03.2019 09:34 Drafted by Sven Petersen Page 1 of 1 Doc.-No.: 107-6-04-02

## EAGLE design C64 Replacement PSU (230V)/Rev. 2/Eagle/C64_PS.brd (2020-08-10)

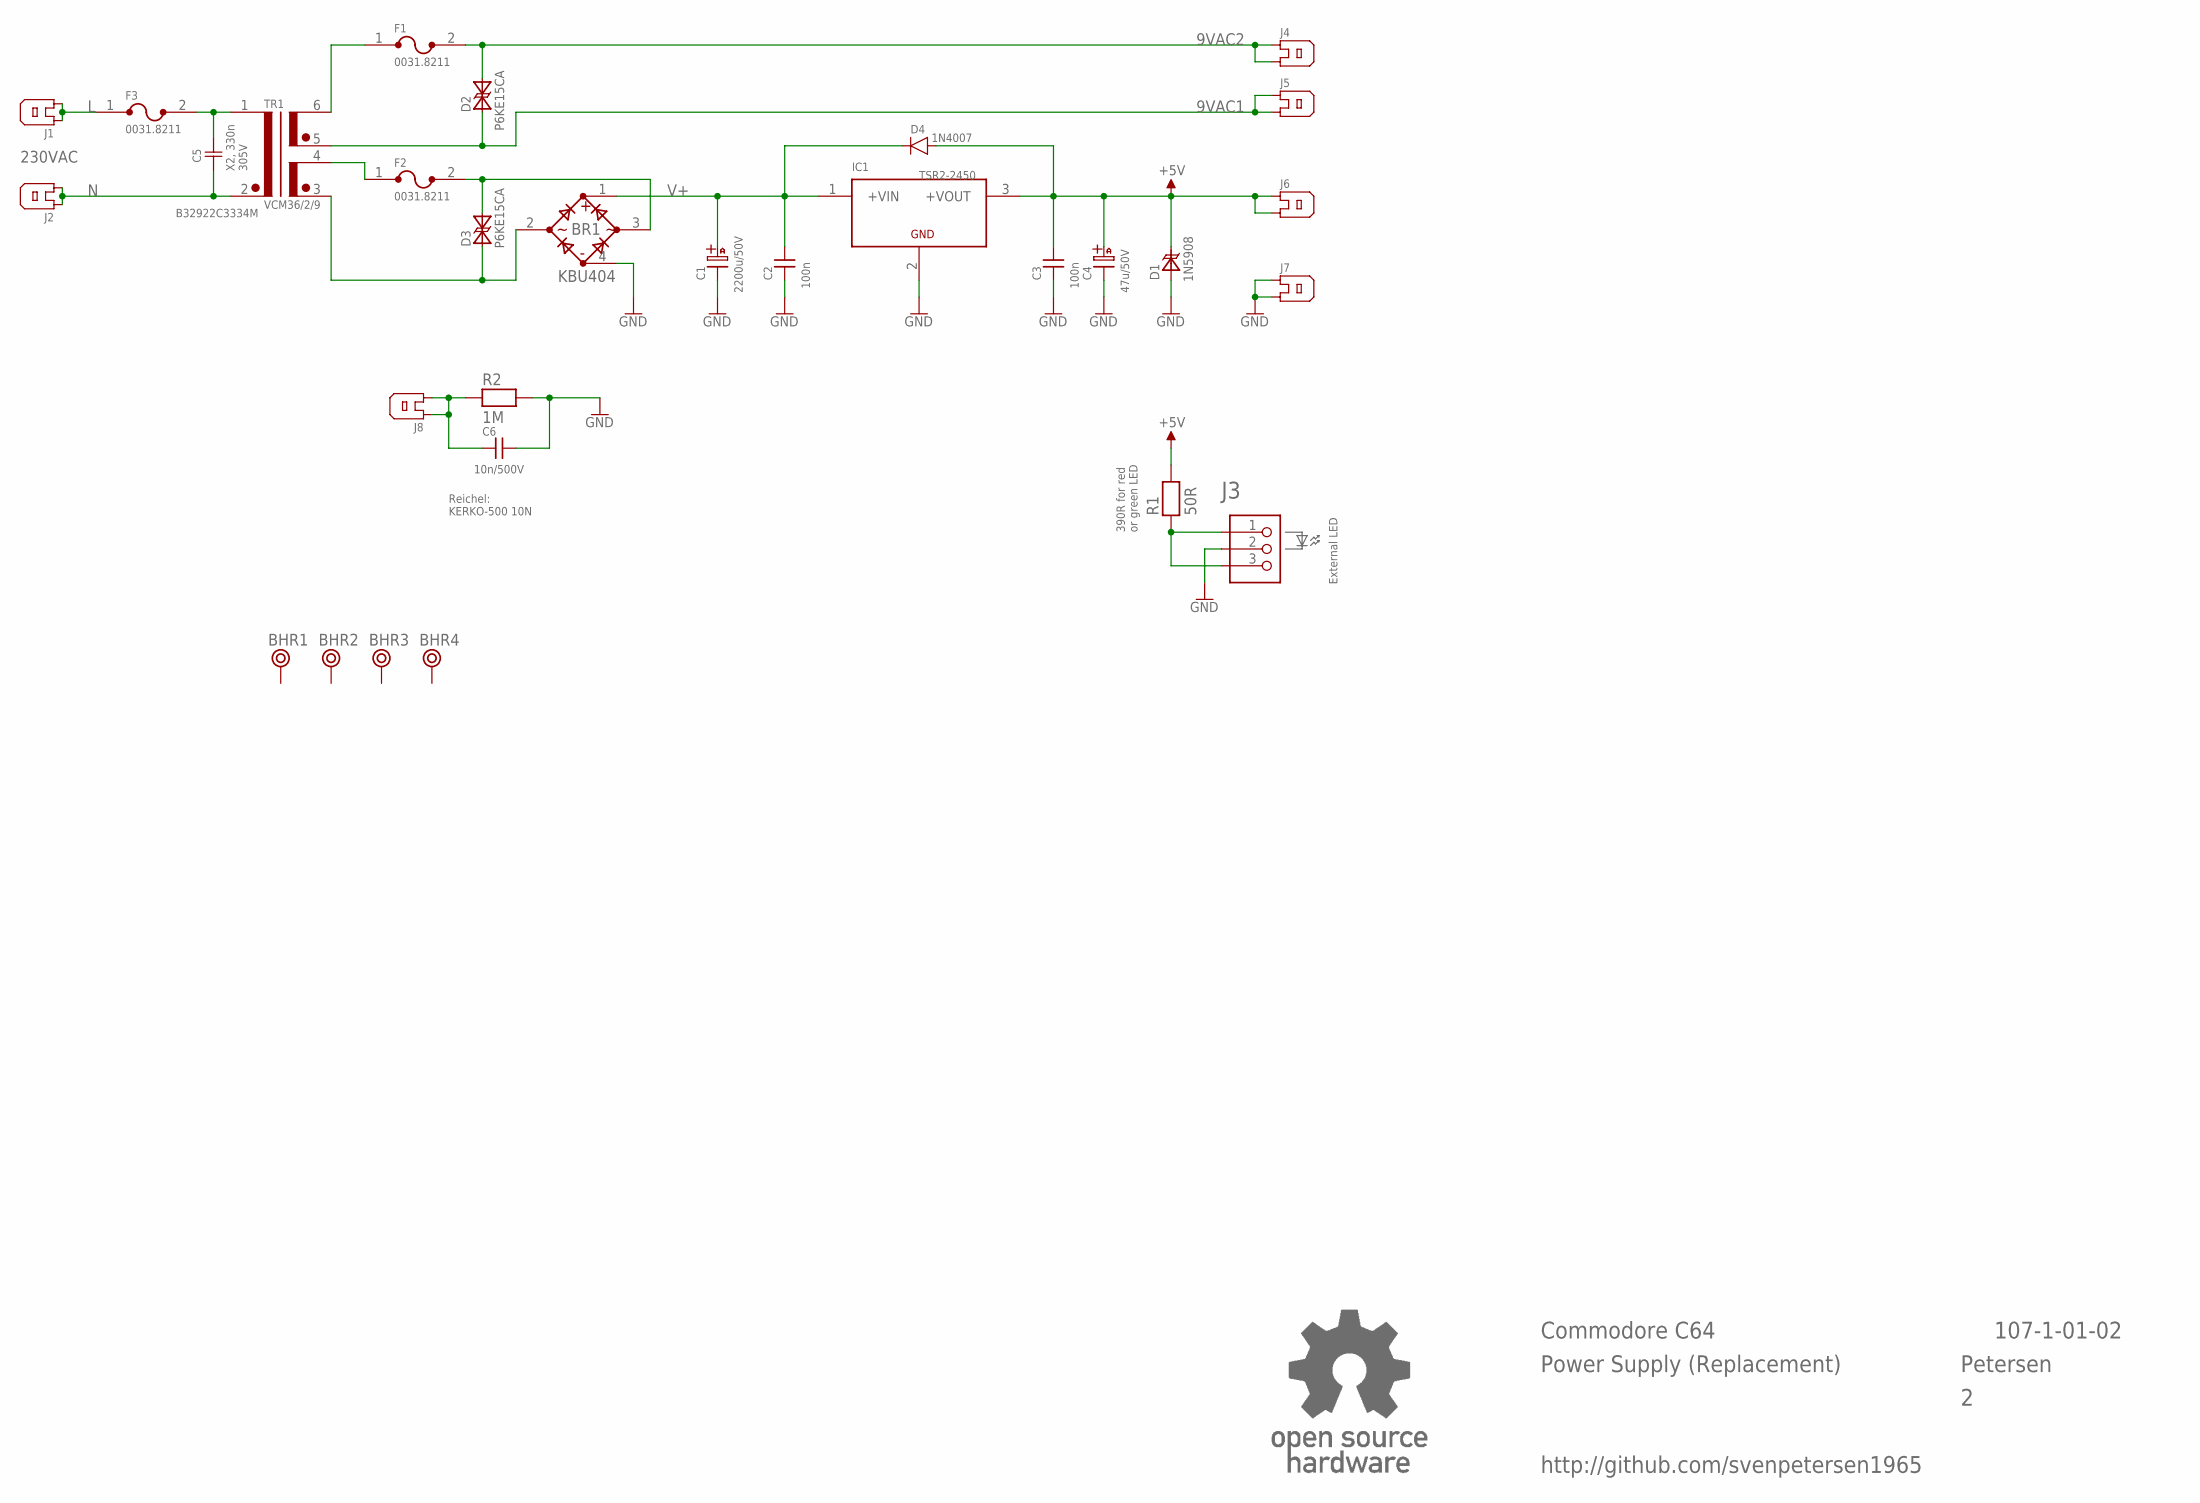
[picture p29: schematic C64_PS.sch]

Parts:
BHR1, BHR2, BHR3, BHR4: BOHR3,3
BR1: KBU404; KBU
C1: 2200u/50V; C18/7,5
C2, C3: 100n; C-5
C4: 47u/50V; C07/2,5
C5: B32922C3334M; C-18X8-RM15
C6: 10n/500V; C-5
D1: 1N5908; CB429
D2, D3: P6KE15CA; CB417
D4: 1N4007; DO-41
F1, F2, F3: 0031.8211
IC1: TSR2-2450; TSR2
J1, J2, J4, J5, J6, J7, J8: FLA6,3
J3: PINHD-1X3; 1X03
R1: 50R; R-10
R2: 1M; R-10
TR1: VCM36/2/9; VCM36_2_9
U$17: OPEN_SOURCE_HW; OPENHW

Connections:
9VAC1: D2.A (A1), J5.1, J5.2, TR1.5 (SEC12)
9VAC2: D2.K (A2), F1.2, J4.1, J4.2
+5V: C3.2, C4.A (+), D1.K, D4.A, IC1.3 (+VOUT), J6.1, J6.2, R1.2
GND: BR1.4 (-), C1.-, C2.1, C3.1, C4.K (-), C6.2, D1.A, IC1.2 (GND), J3.2, J7.1, J7.2, R2.2
L: F3.1, J1.1, J1.2
N: C5.1, J2.1, J2.2, TR1.2 (PRI2)
unnamed: F1.1, TR1.6 (SEC11)
unnamed: J3.1, J3.3, R1.1
unnamed: F2.1, TR1.4 (SEC21)
unnamed: BR1.2 (AC1), D3.A (A1), TR1.3 (SEC22)
unnamed: BR1.3 (AC2), D3.K (A2), F2.2
unnamed: C5.2, F3.2, TR1.1 (PRI1)
PE: C6.1, J8.1, J8.2, R2.1
V+: BR1.1 (+), C1.+, C2.2, D4.K, IC1.1 (+VIN)

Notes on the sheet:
230VAC
External LED
X2, 330n 305V
Commodore C64
Power Supply (Replacement)
107-1-01-02
Petersen
390R for red or green LED
Reichel: KERKO-500 10N
http://github.com/svenpetersen1965

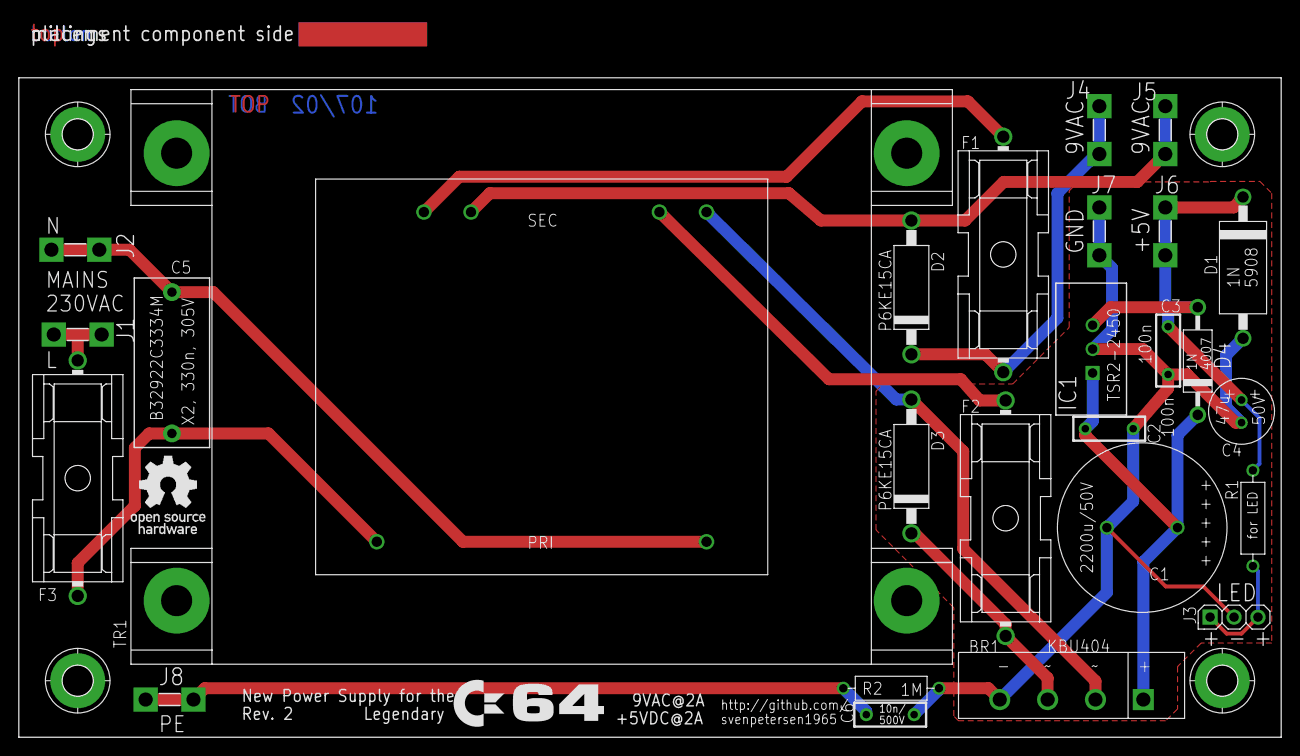
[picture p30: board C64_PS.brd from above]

Board: 2 copper layers, 134.0 x 70.0 mm, 34 parts (0 on the bottom side), 14 nets.

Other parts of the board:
U$13: PCB-TITLE/
U$14: 2LAYER
U$15: C64_LOGO

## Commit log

2019-03-15 Initial file upload
    [C64_PS.brd, C64_PS.sch, C64_PS_BOM_v2_0.xlsx]
2020-06-09 BOM calculation added
    Prices of June 9th, 2020
    [C64_PS_BOM_v2_0-calc.xlsx]
2020-08-10 Silk Screen Update
    [C64_PS.brd, C64_PS.sch]
2022-02-26 Gerbers removed
